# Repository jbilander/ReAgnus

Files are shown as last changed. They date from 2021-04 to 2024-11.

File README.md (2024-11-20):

# ReAgnus
A drop-in replacement PCB for the Amiga Agnus chip

***

Rev. 2D, design using a [PLCC-84 homebrew plug](https://github.com/jbilander/PLCC-84-plug)

<a href="images/ReAgnus_rev2d_pic1.jpg">
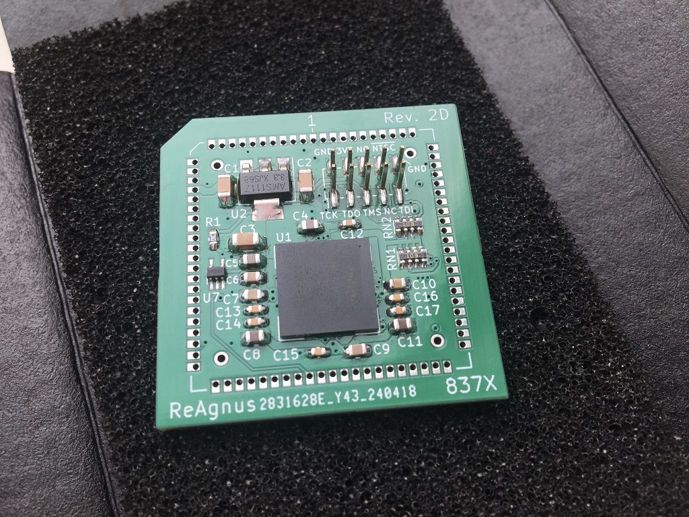
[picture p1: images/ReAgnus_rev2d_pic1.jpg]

</a>
<a href="images/ReAgnus_rev2d_pic2.jpg">
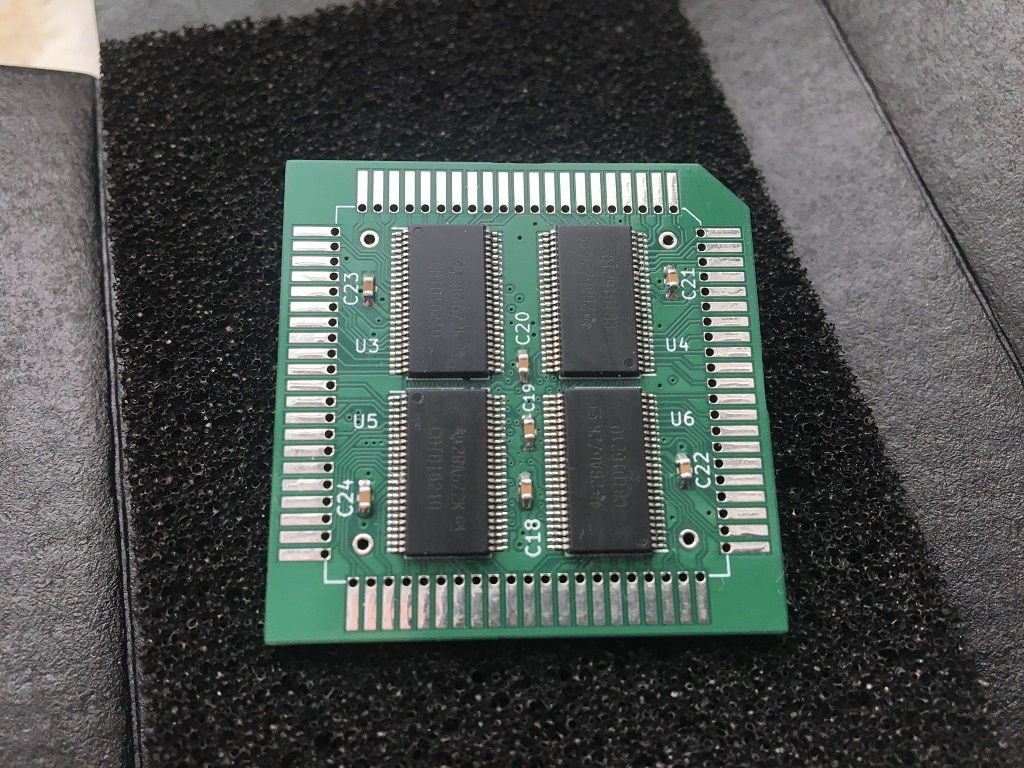
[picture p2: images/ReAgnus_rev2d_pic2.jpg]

</a>
<br />
<a href="images/ReAgnus_rev2d_pic3.jpg">
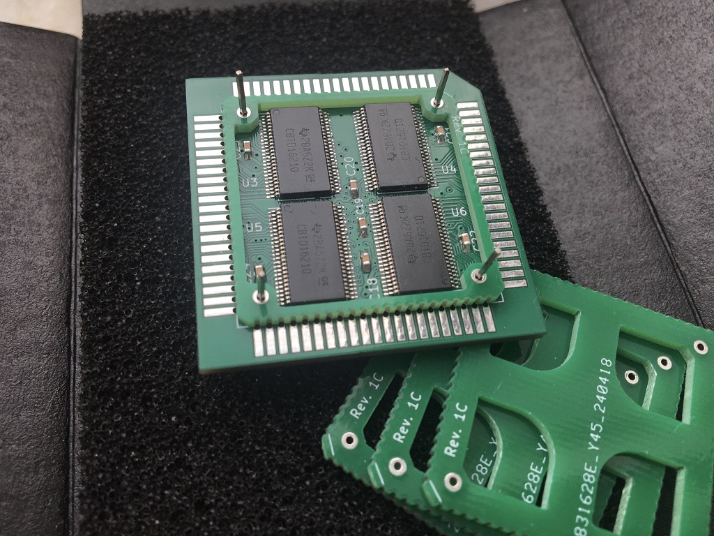
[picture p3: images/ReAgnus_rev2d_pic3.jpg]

</a>
<a href="images/ReAgnus_rev2d_pic4.jpg">
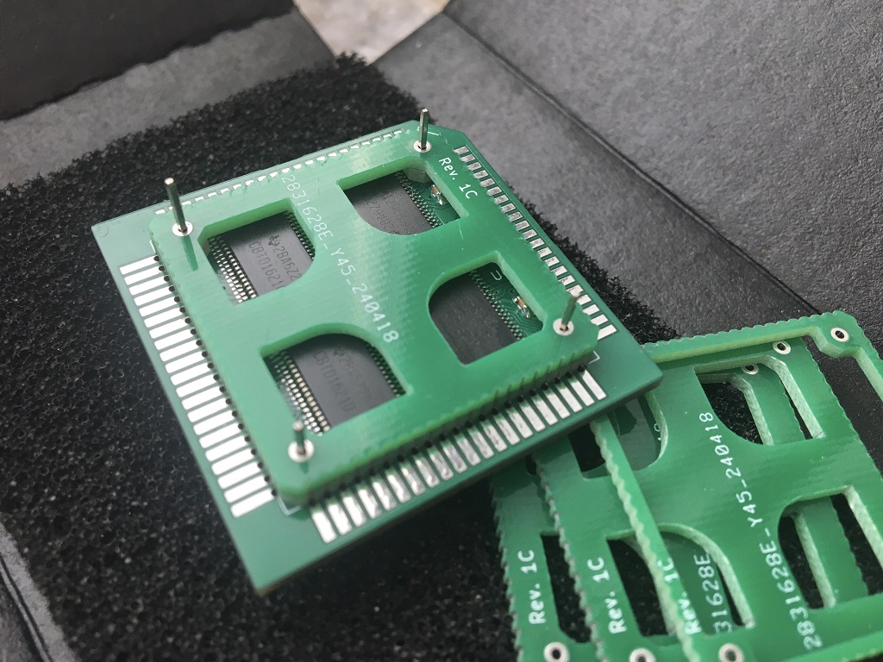
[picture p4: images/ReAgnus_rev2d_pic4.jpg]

</a>
<a href="images/ReAgnus_rev2d_pic5.jpg">
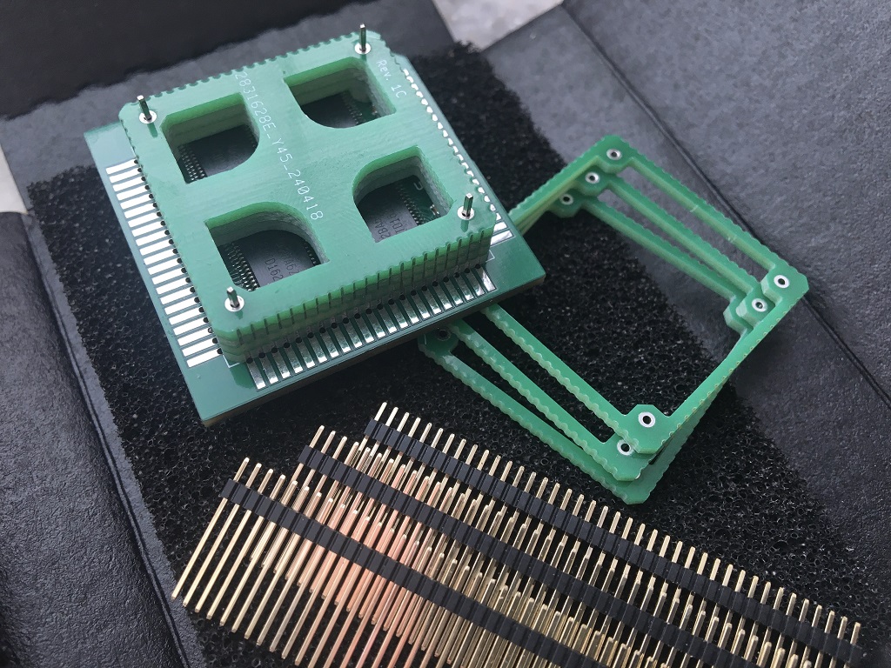
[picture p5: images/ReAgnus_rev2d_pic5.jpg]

</a>

***
FPGA pin assignment:

<a href="images/pin_assignment_rev2e.jpg">
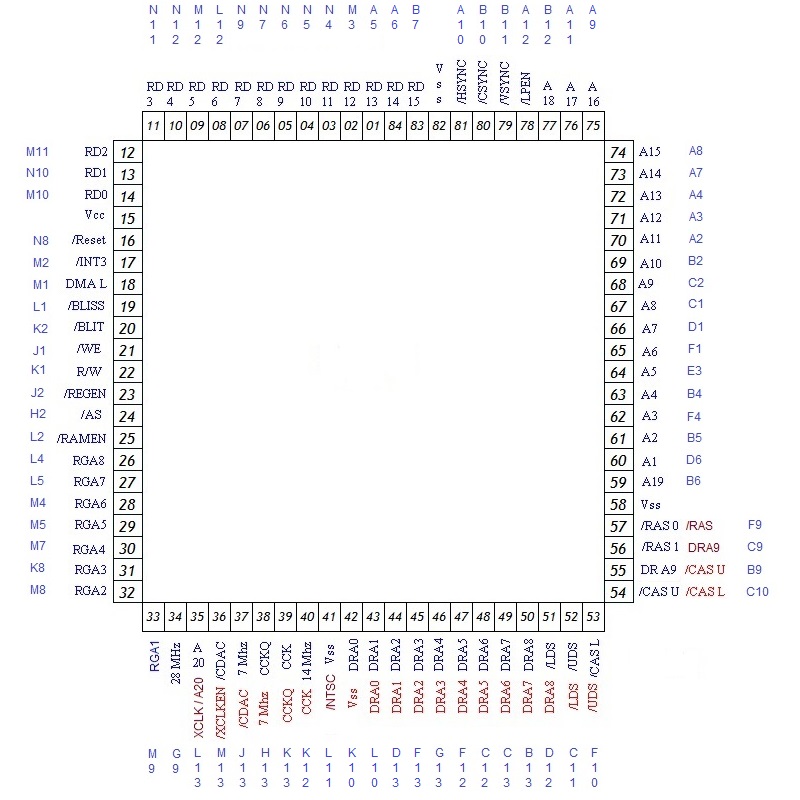
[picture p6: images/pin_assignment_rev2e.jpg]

</a>

***

Rev. 2B, design using a PLCC-84-plug
<br />
<br />

<a href="images/ReAgnus_rev2b_pic1.png">
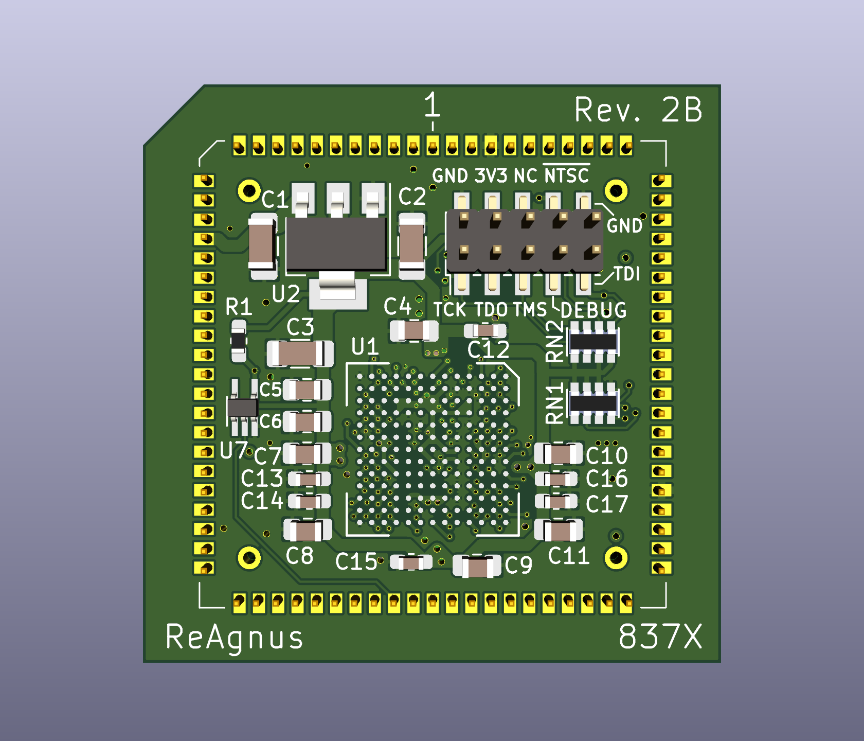
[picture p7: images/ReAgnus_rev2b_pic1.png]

</a>
<a href="images/ReAgnus_rev2b_pic2.png">
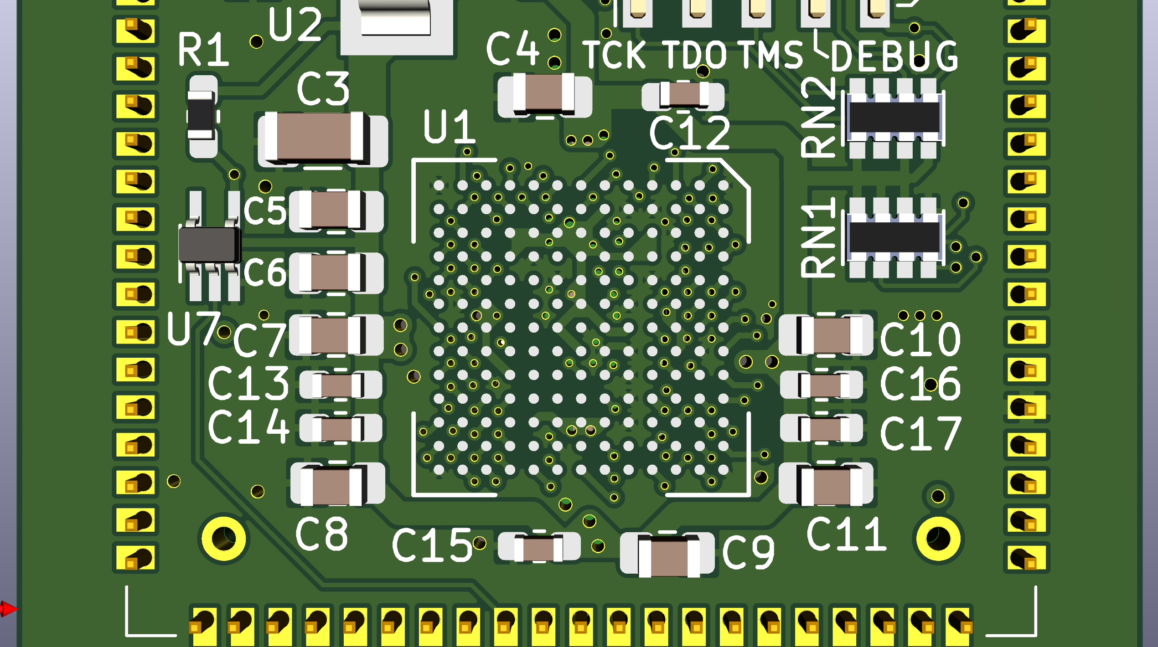
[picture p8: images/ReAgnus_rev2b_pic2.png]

</a>
<a href="images/ReAgnus_rev2b_pic9.png">
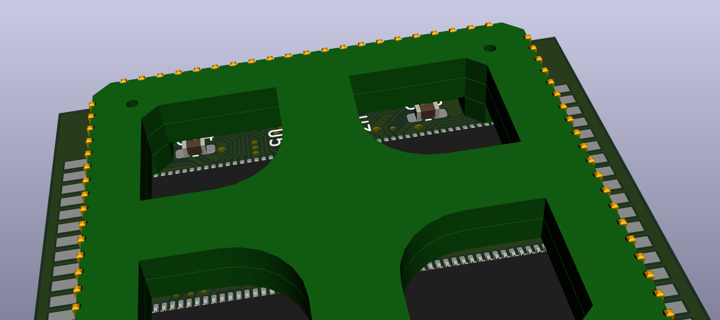
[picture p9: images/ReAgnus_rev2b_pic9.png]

</a>
<br />
<a href="images/ReAgnus_rev2b_pic7.png">
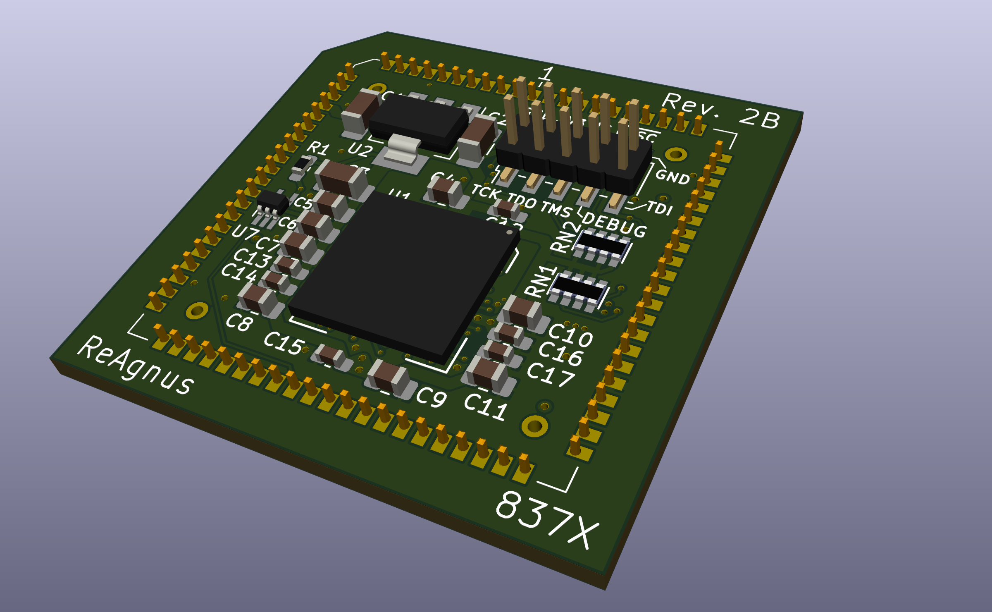
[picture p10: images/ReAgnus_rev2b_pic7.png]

</a>
<a href="images/ReAgnus_rev2b_pic8.png">
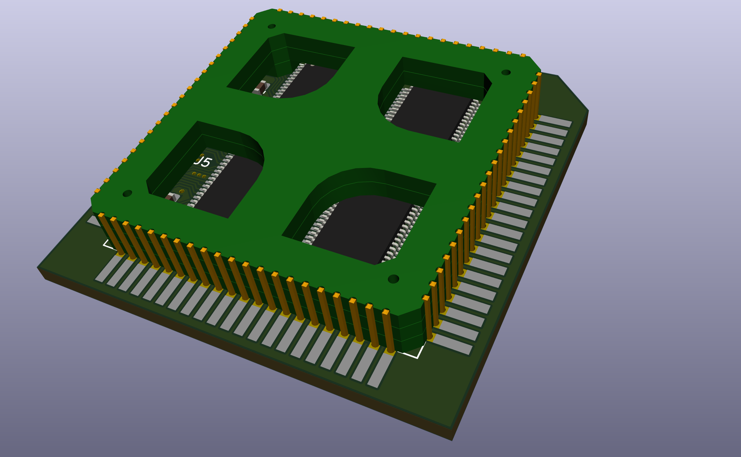
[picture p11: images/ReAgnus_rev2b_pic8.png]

</a>
<br />

***

When ordering from JLCPCB select:

Specify Layer Sequence: Yes

    L1(Top layer):    F_Cu.gbr
    L2(Inner layer1): GND_Cu.gbr
    L3(Inner layer2): VCC_Cu.gbr
    L4(Bottom layer): B_Cu.gbr

Remove Order Number: 

    Specify a location

This will notify JLC where to put the order number, they will replace the "JLCJLCJLCJLC" silkscreen label.

***

<a href="images/ReAgnus_rev2b_pic11.png">
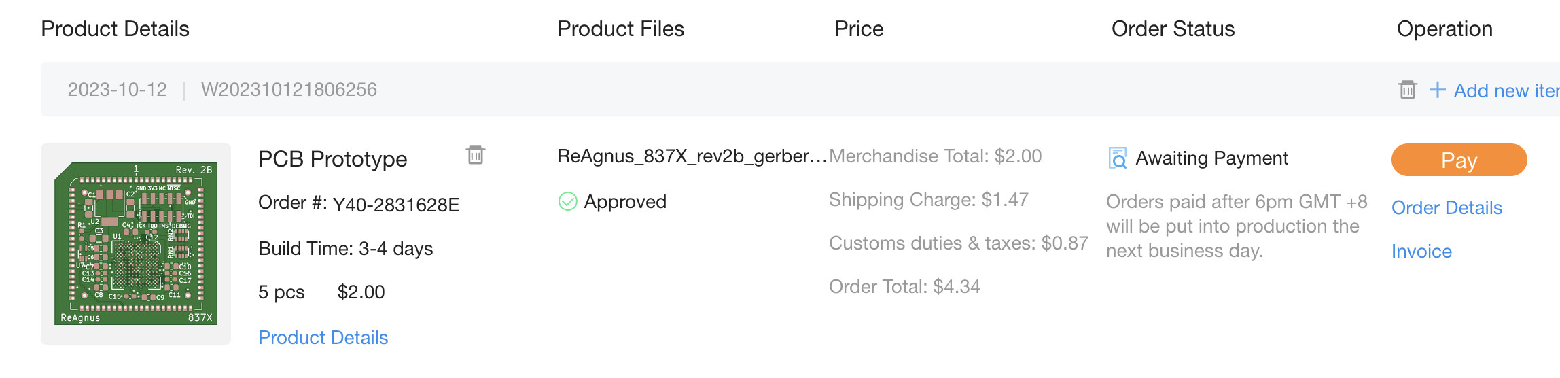
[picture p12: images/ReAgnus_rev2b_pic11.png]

</a>
<br />
<a href="images/ReAgnus_rev2b_pic10.png">
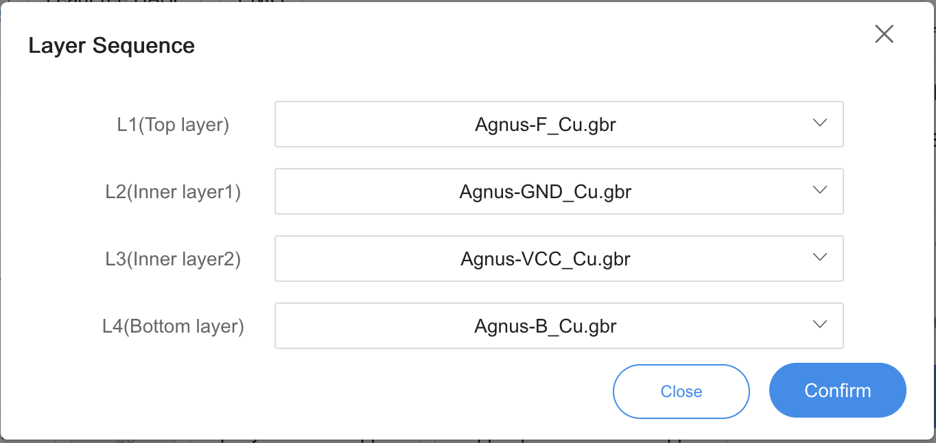
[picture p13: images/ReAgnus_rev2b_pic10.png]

</a>
<br />
<a href="images/ReAgnus_rev2b_pic4.png">
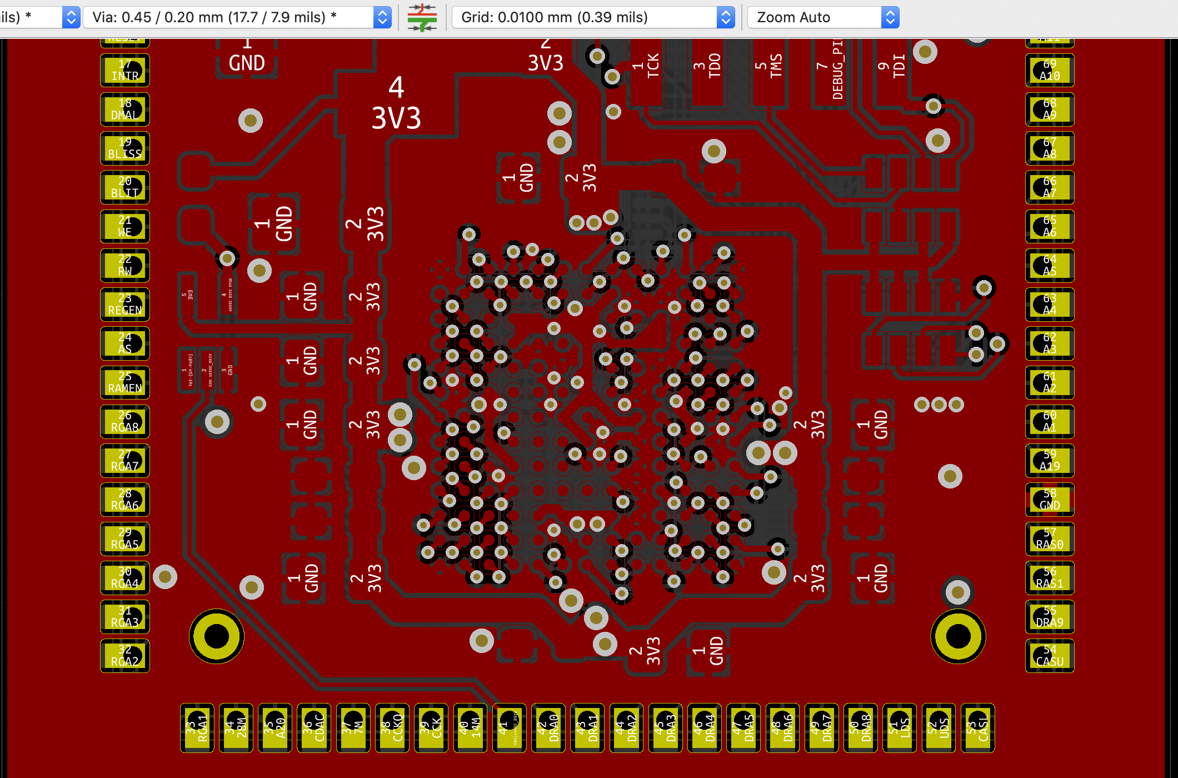
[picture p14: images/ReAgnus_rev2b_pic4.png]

</a>
<a href="images/ReAgnus_rev2b_pic5.png">
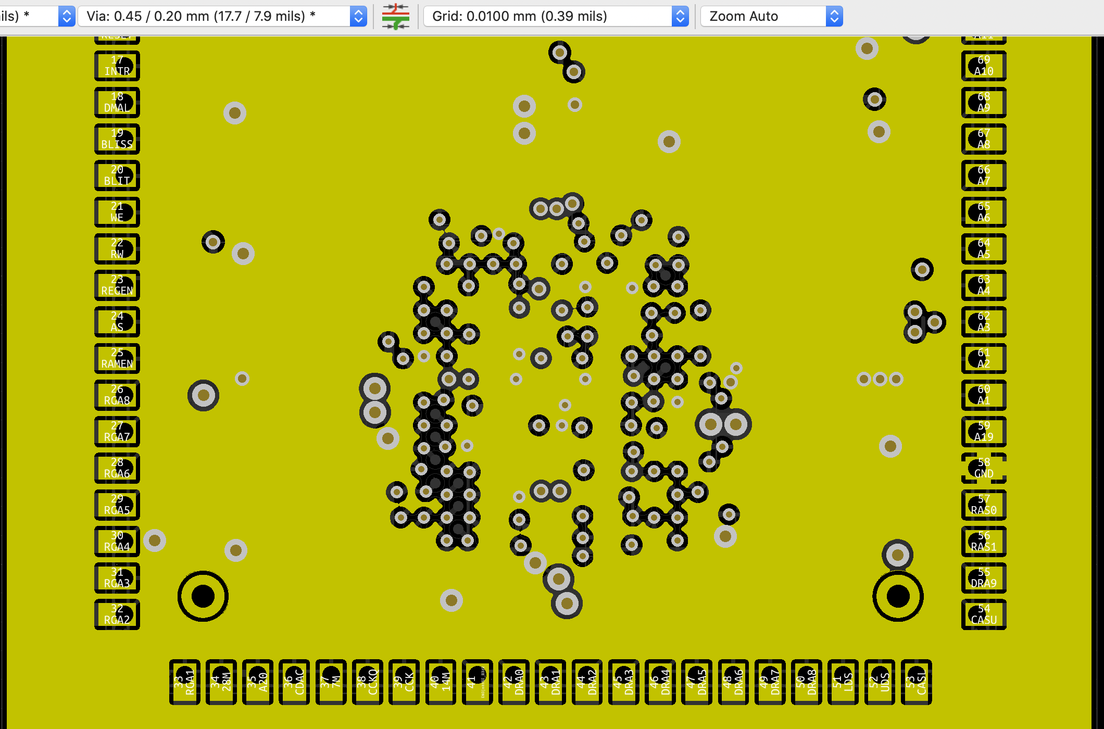
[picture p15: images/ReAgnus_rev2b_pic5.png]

</a>
<br />
<a href="images/ReAgnus_rev2b_pic6.png">
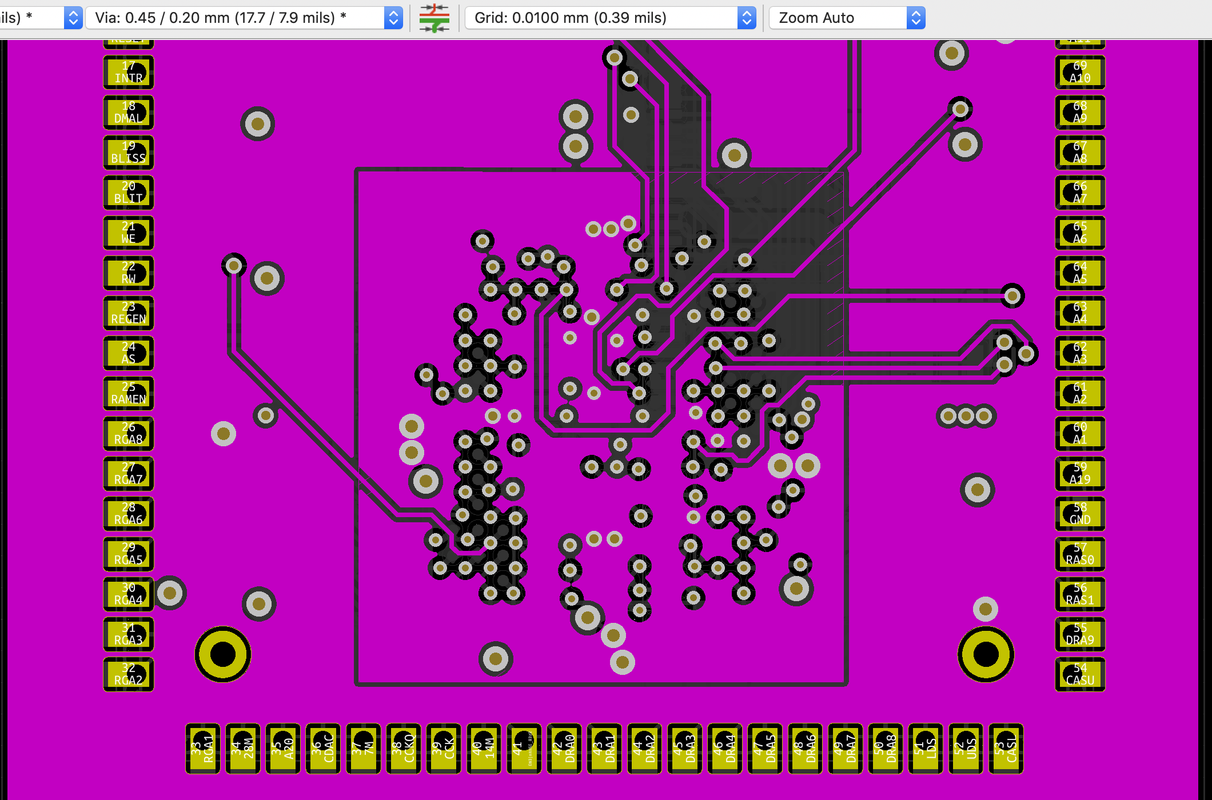
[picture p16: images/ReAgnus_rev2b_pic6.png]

</a>
<a href="images/ReAgnus_rev2b_pic3.png">
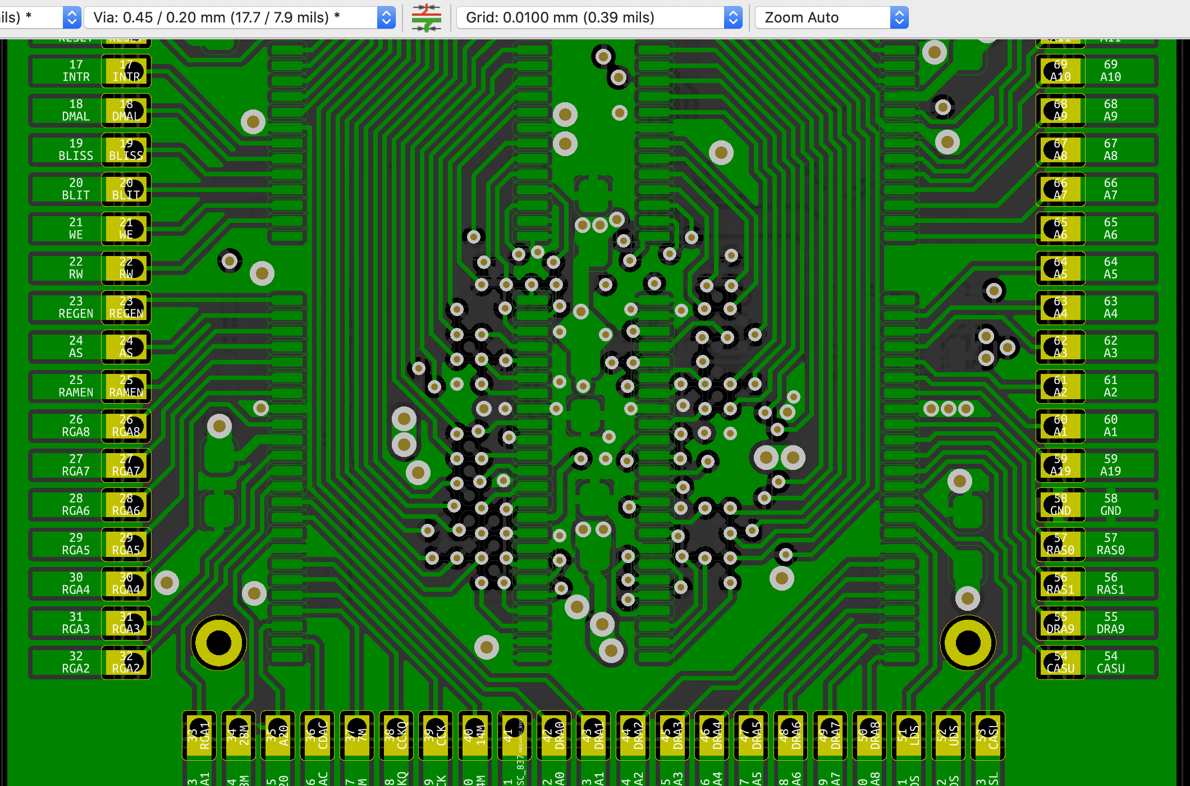
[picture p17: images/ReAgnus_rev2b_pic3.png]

</a>

***

Building Rev. 2B

<a href="images/ReAgnus_rev2b_pic12.jpg">
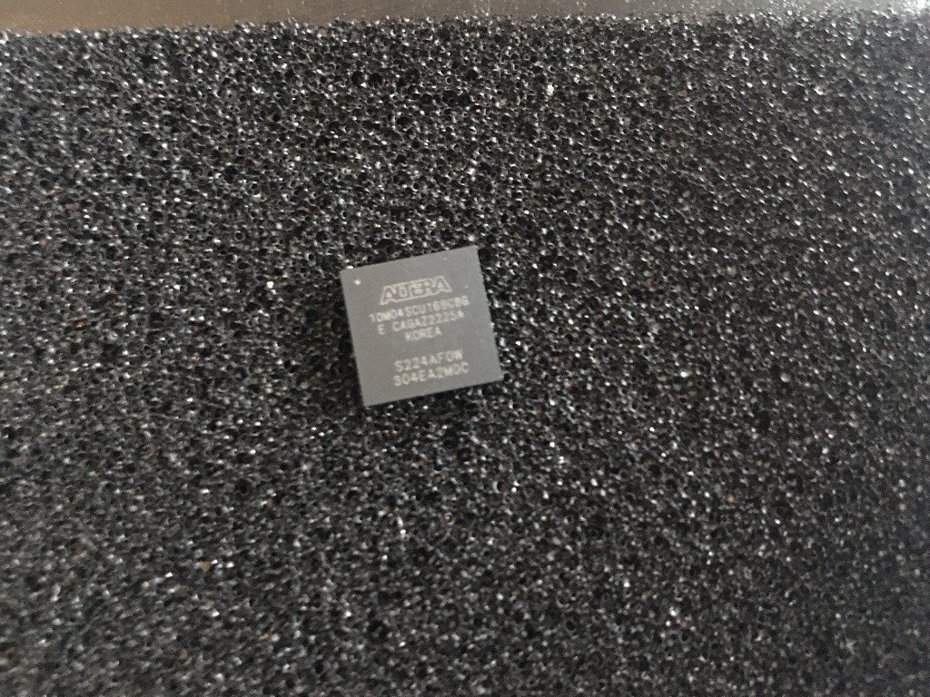
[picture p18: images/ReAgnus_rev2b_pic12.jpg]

</a>
<a href="images/ReAgnus_rev2b_pic13.jpg">
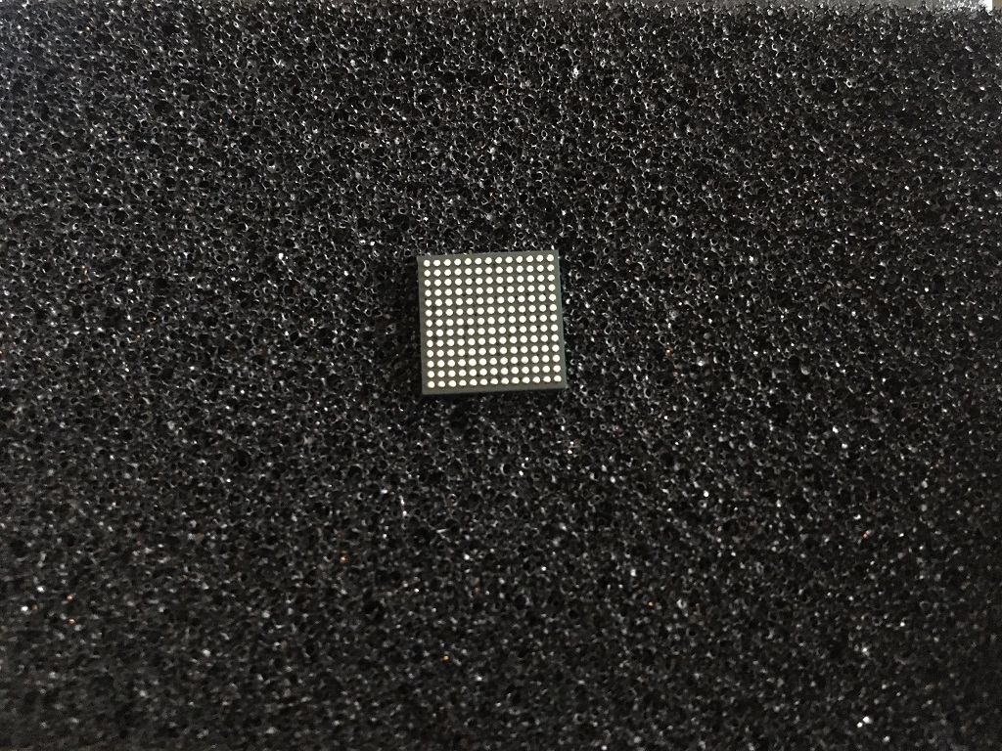
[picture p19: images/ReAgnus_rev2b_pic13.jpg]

</a>
<a href="images/ReAgnus_rev2b_pic14.jpg">
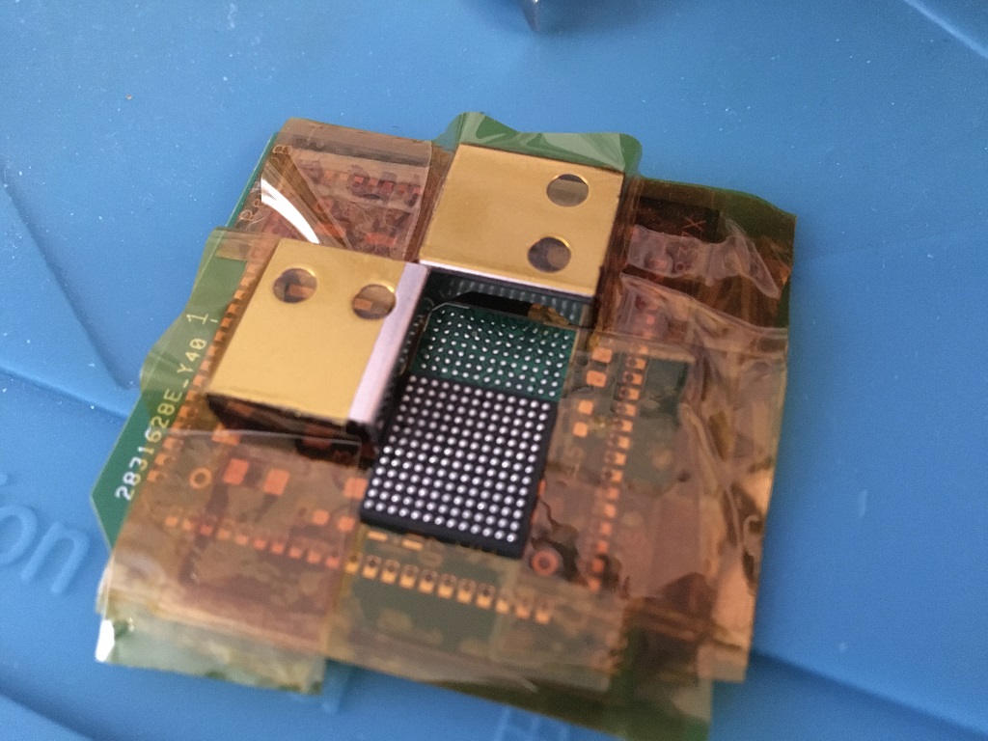
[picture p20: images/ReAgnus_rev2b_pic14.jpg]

</a>
<br />
<a href="images/ReAgnus_rev2b_pic15.jpg">
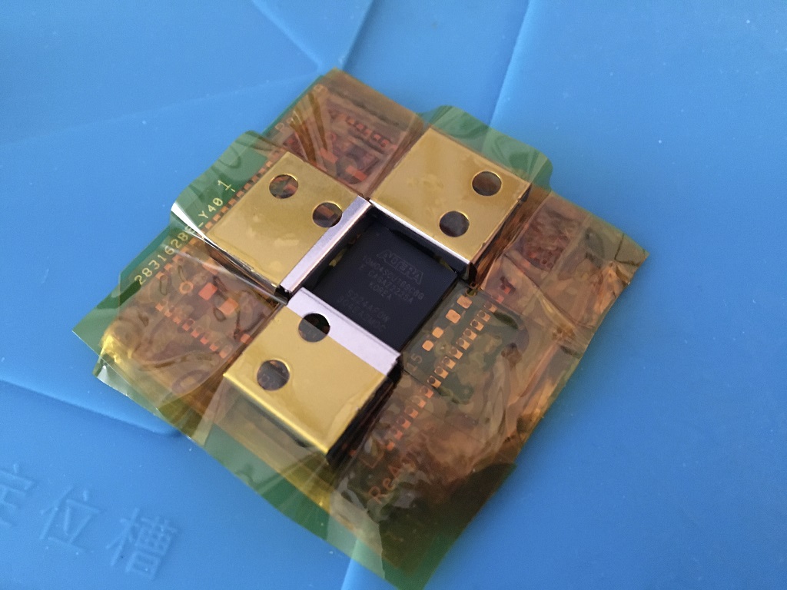
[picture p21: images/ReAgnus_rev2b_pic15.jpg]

</a>
<a href="images/ReAgnus_rev2b_pic16.jpg">
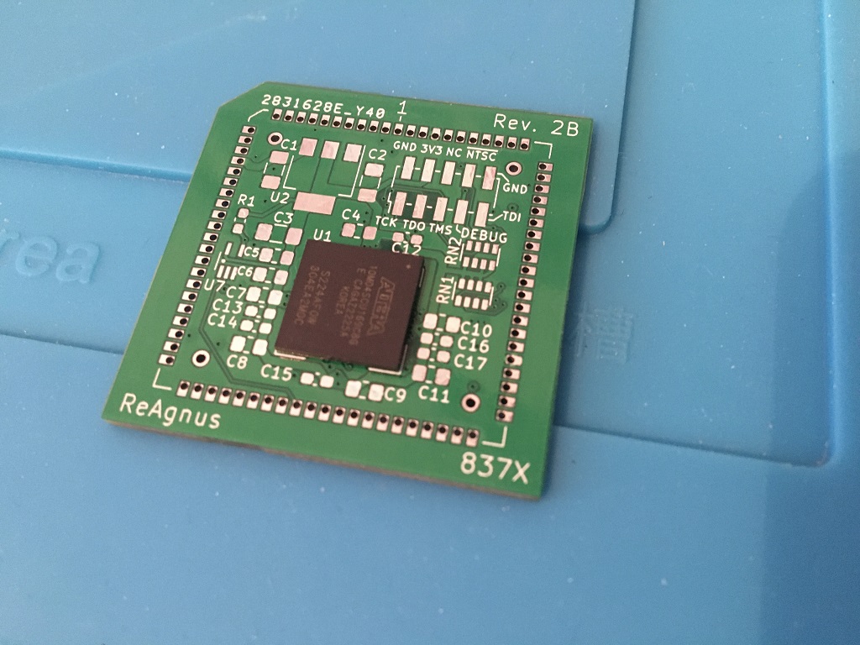
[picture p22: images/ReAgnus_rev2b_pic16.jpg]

</a>
<a href="images/ReAgnus_rev2b_pic17.jpg">
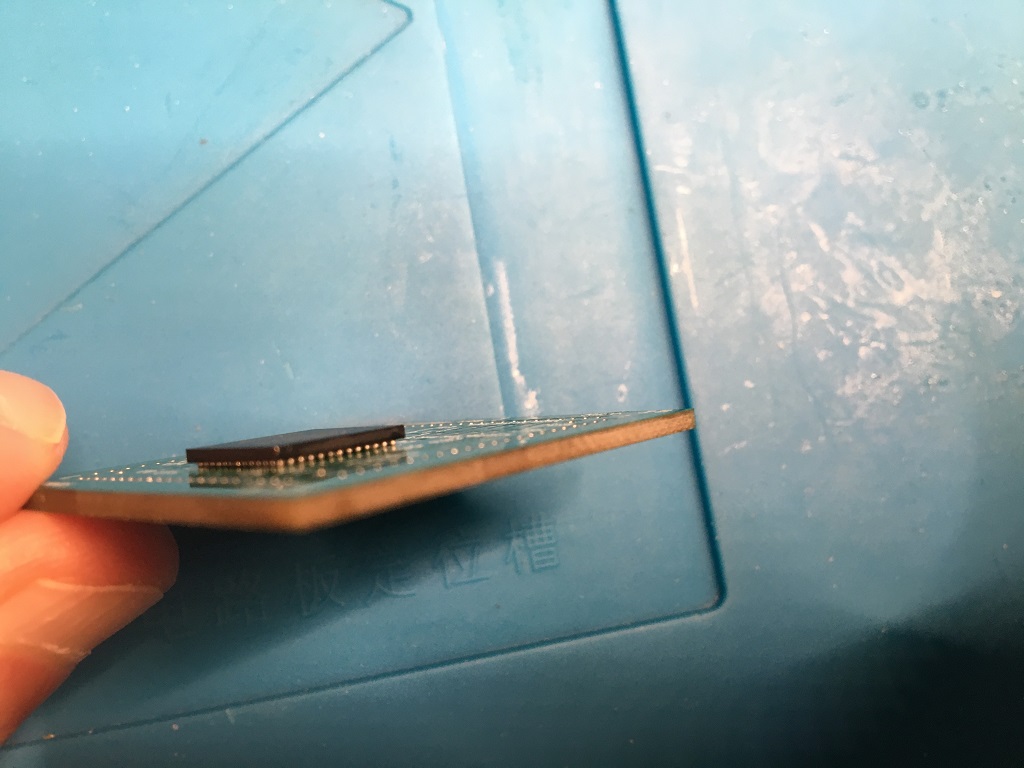
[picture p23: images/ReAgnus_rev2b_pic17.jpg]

</a>
<br />
<a href="images/ReAgnus_rev2b_pic18.jpg">
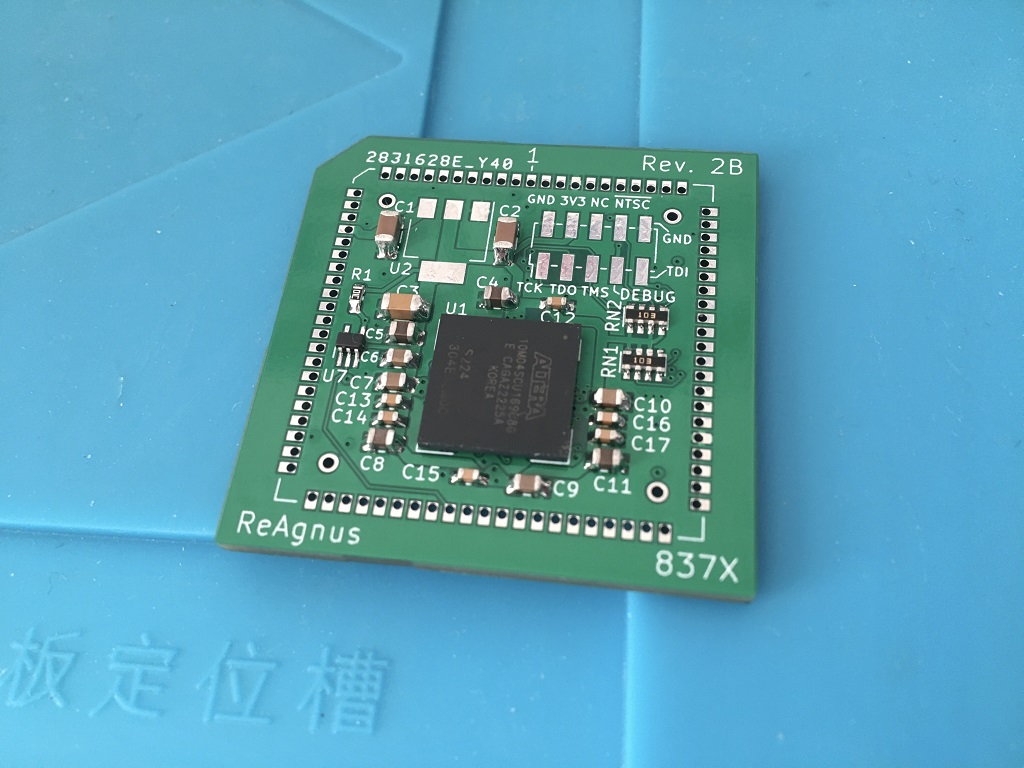
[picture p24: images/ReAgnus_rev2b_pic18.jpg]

</a>
<a href="images/ReAgnus_rev2b_pic19.jpg">
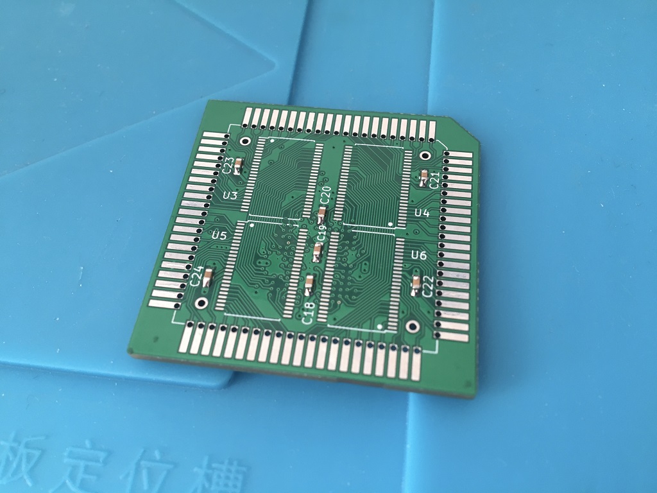
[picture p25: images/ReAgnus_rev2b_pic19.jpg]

</a>
<a href="images/ReAgnus_rev2b_pic20.jpg">
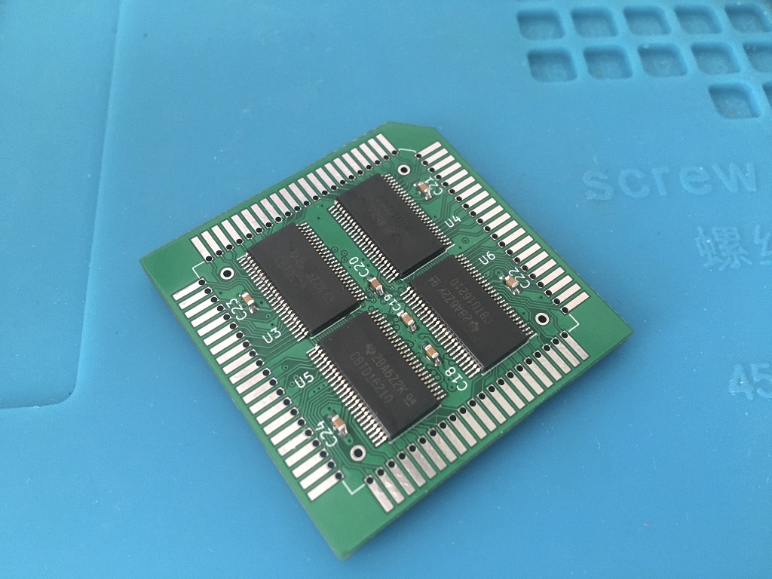
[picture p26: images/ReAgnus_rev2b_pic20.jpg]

</a>
<br />
<a href="images/ReAgnus_rev2b_pic21.jpg">
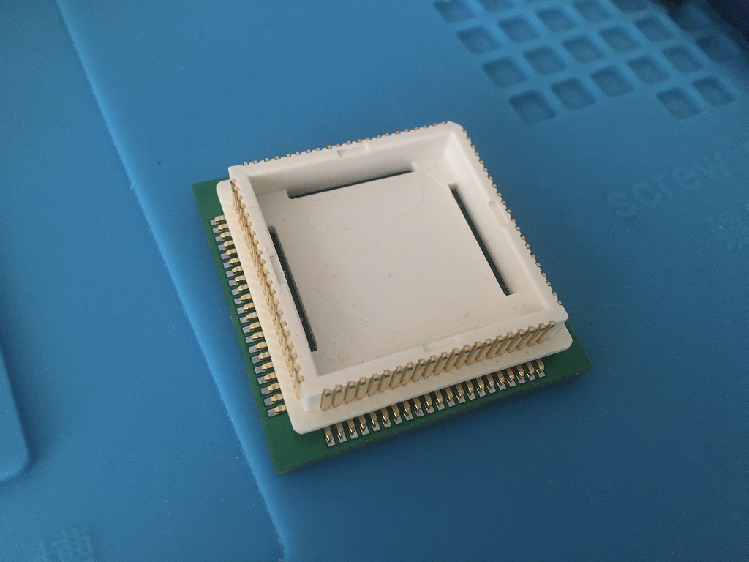
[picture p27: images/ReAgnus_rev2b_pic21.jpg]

</a>
<a href="images/ReAgnus_rev2b_pic22.jpg">
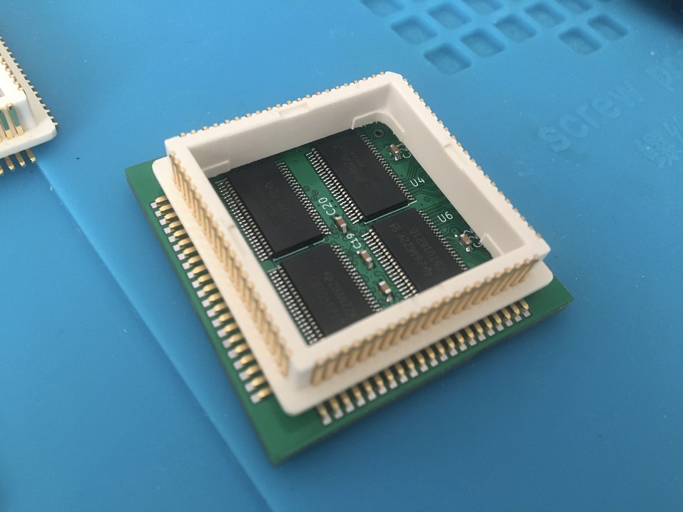
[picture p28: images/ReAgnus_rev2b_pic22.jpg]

</a>
<a href="images/ReAgnus_rev2b_pic23.jpg">
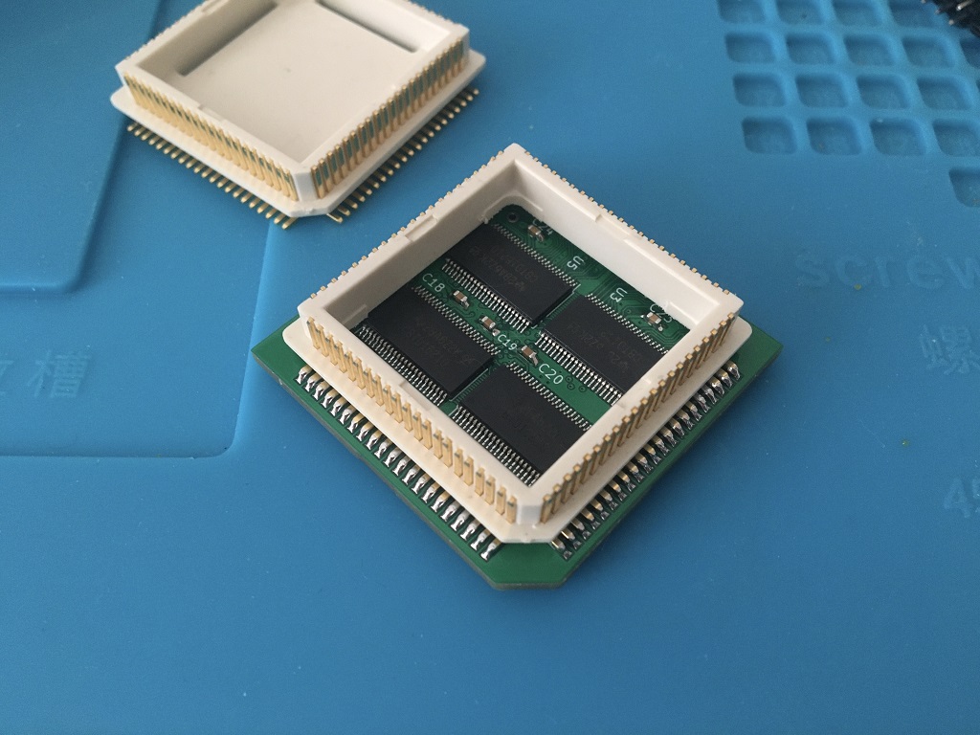
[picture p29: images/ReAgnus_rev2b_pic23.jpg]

</a>
<br />
<a href="images/ReAgnus_rev2b_pic24.jpg">
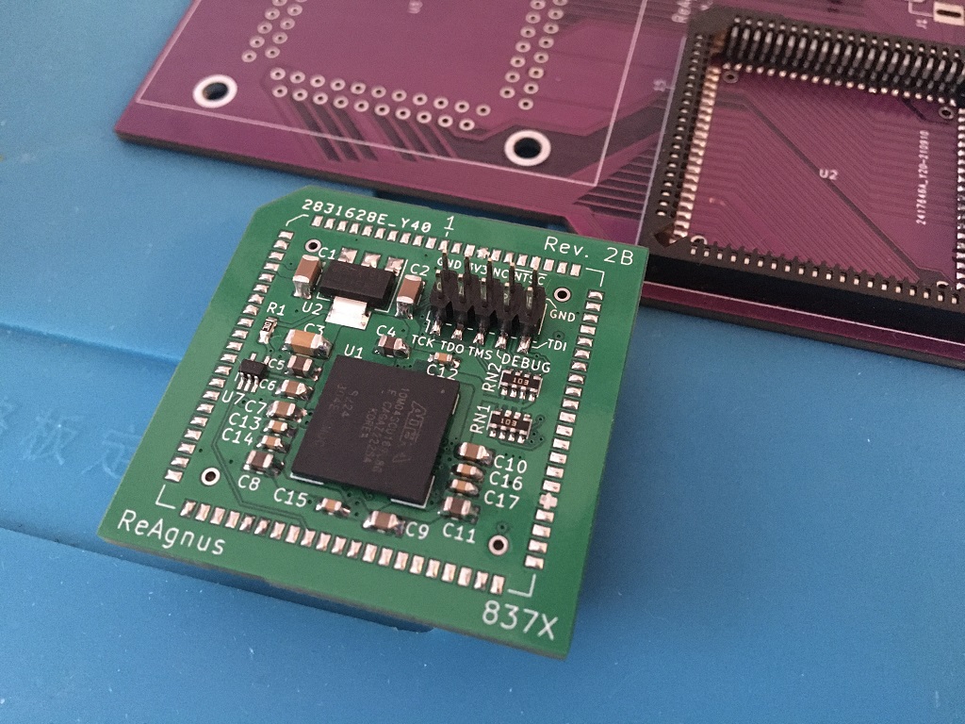
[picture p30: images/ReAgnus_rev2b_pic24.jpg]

</a>

***

<br />
REV 1A
<br />
<a href="images/screenshot_pic1.png">
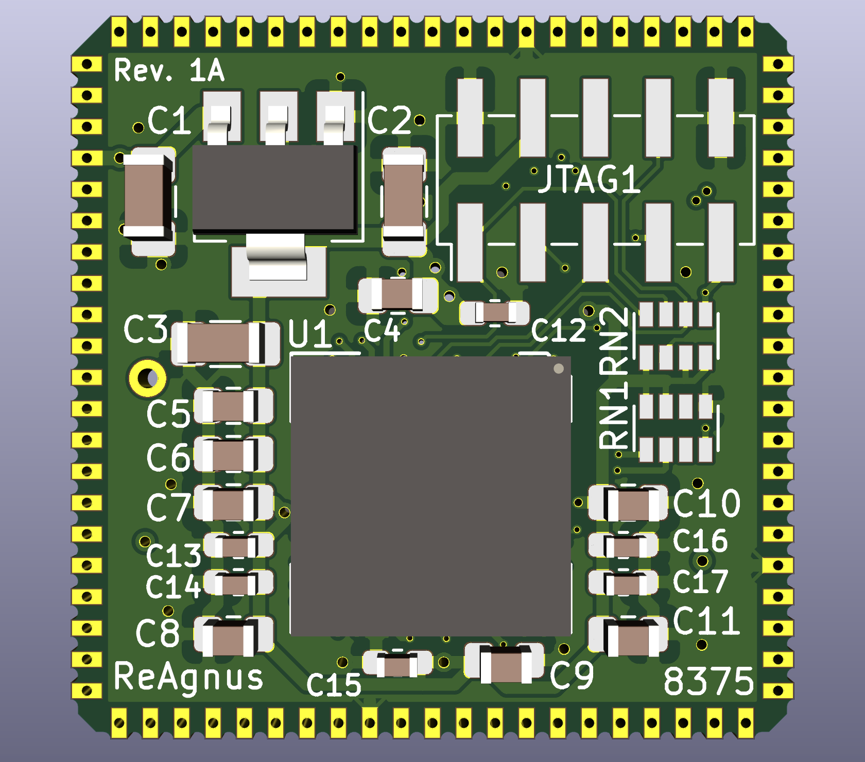
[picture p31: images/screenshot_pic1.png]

</a>
<a href="images/screenshot_pic2.png">
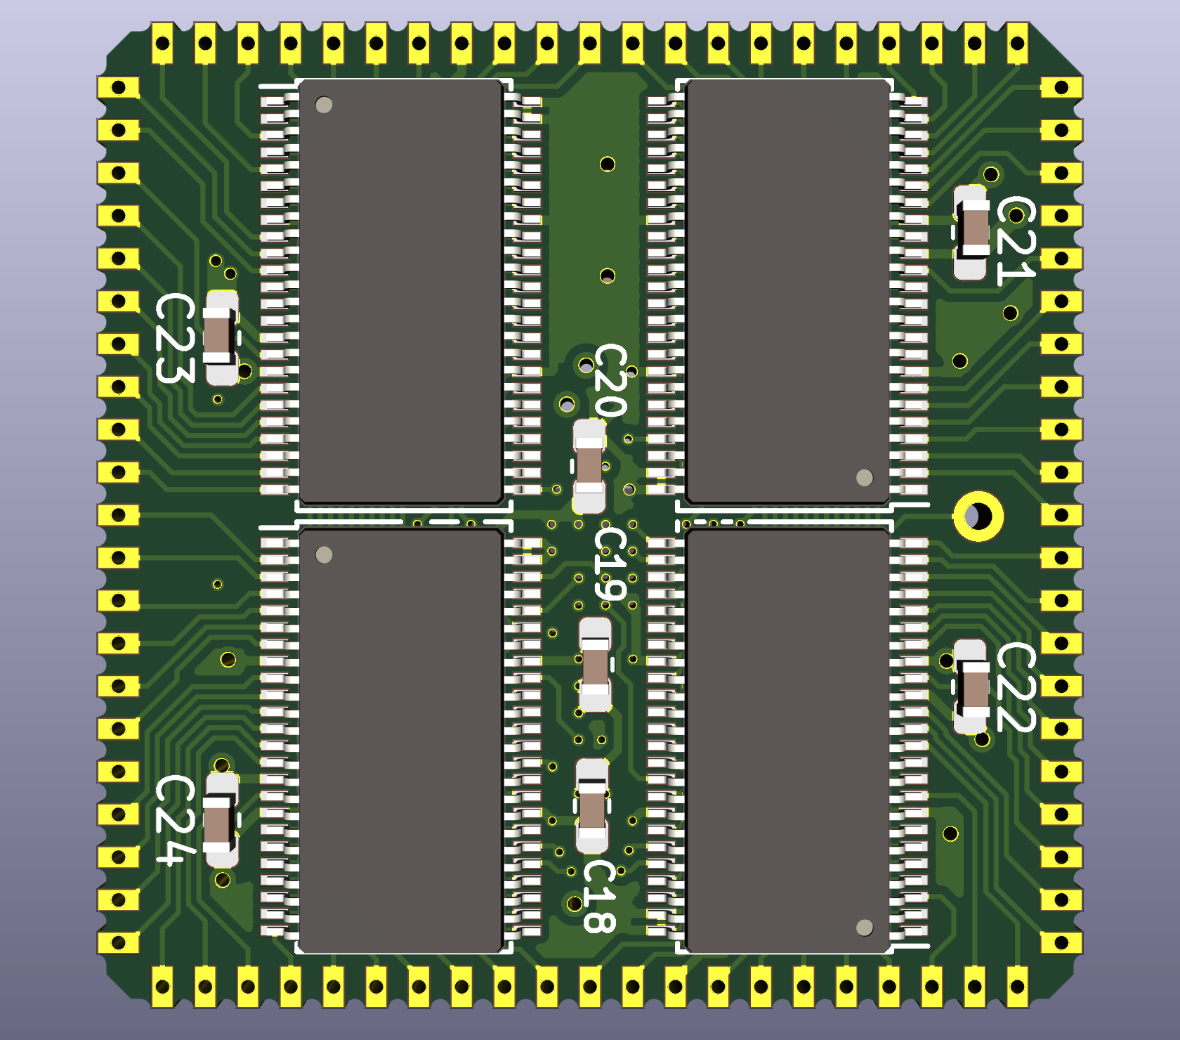
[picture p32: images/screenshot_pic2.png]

</a>

<br />
REV 1B
<br />
<a href="images/screenshot_pic3.png">
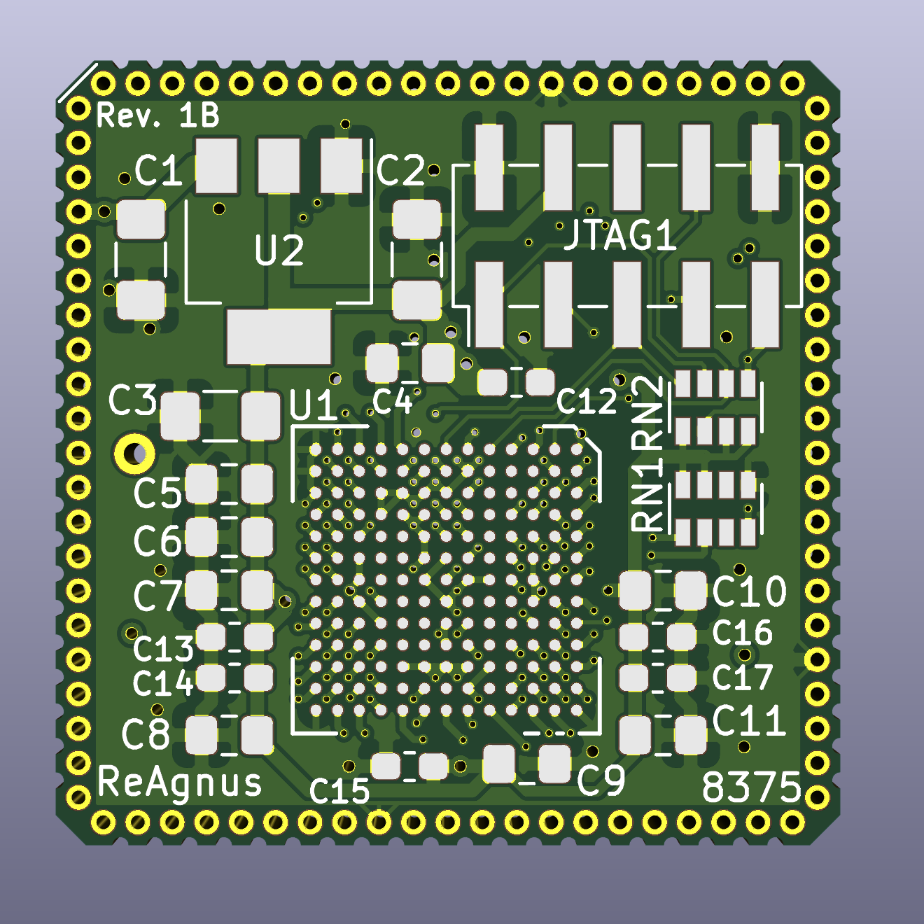
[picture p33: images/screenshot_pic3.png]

</a>
<a href="images/screenshot_pic4.png">
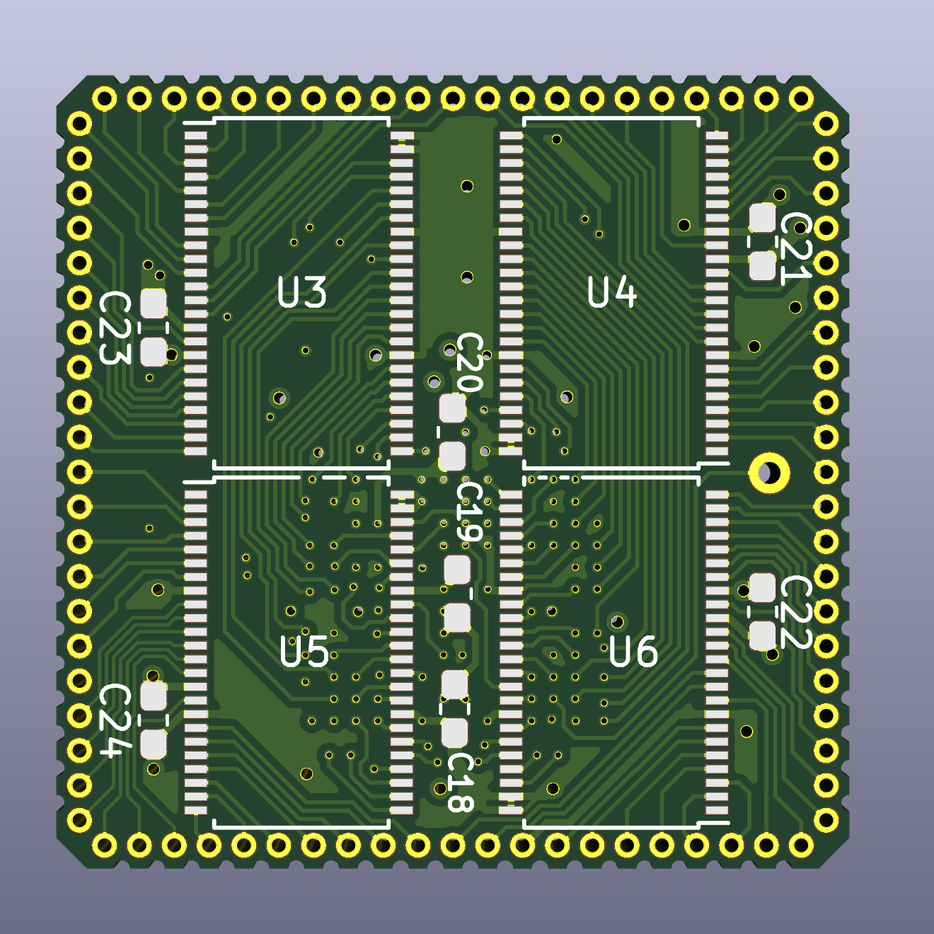
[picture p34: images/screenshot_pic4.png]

</a>

<br />
<a href="images/ReAgnus_four_in_one.jpg">
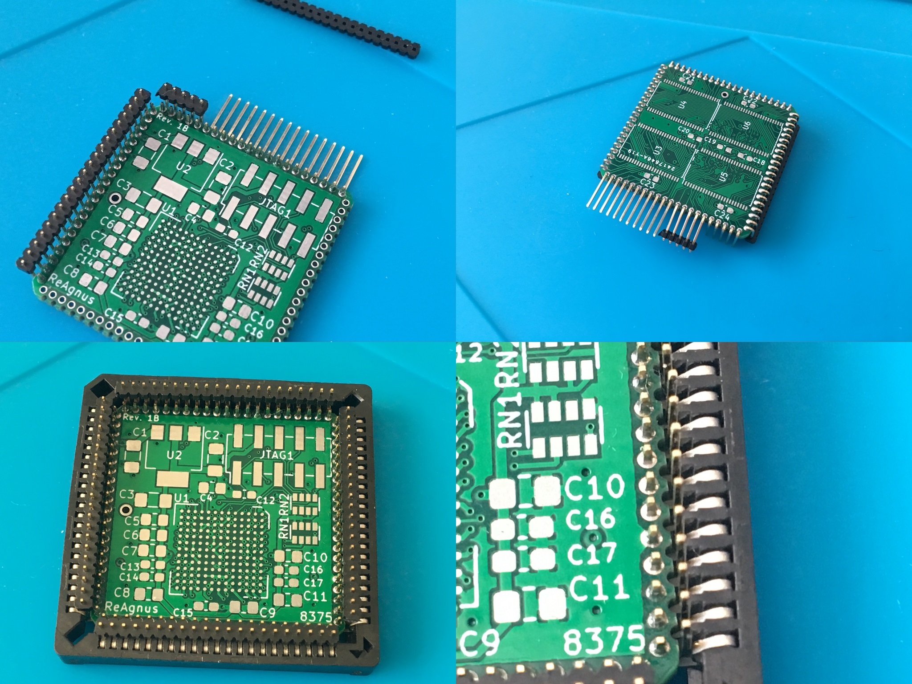
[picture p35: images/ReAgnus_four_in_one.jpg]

</a>
<a href="images/screenshot_pic5.png">
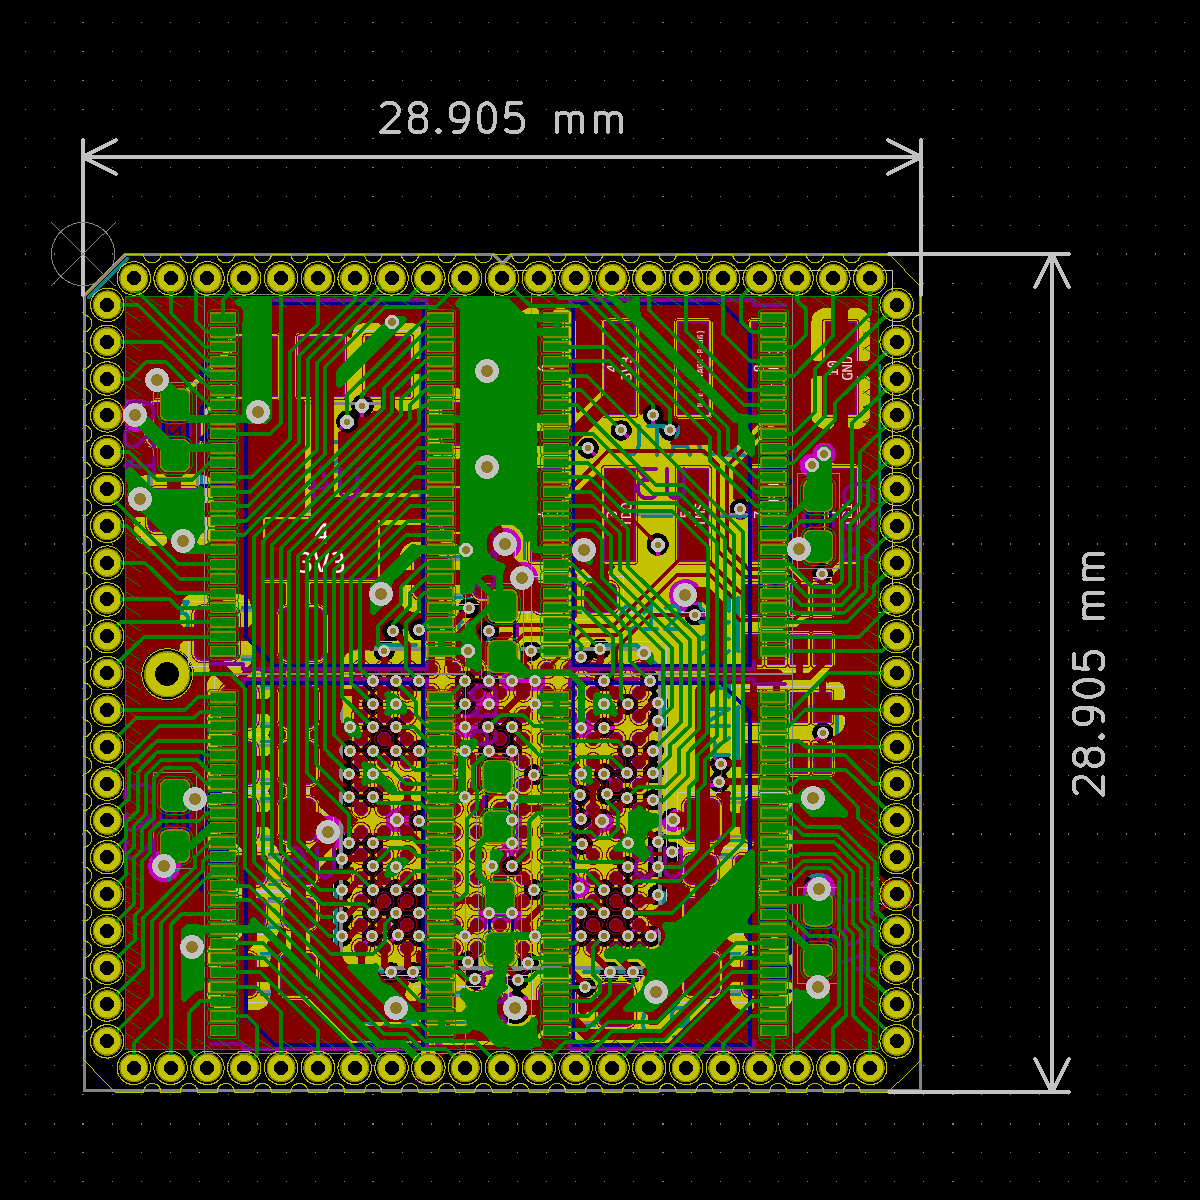
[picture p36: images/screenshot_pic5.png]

</a>

***

<br />
<a href="images/ReAgnus_pic1.jpg">
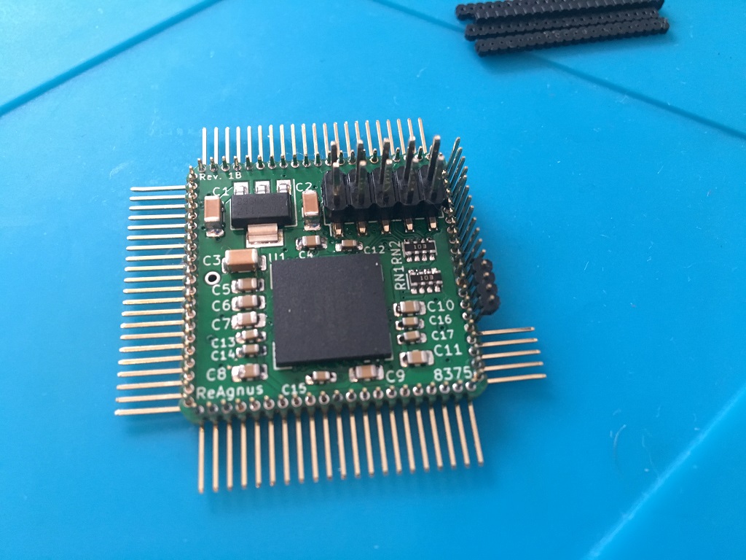
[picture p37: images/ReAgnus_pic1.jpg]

</a>
<a href="images/ReAgnus_pic2.jpg">
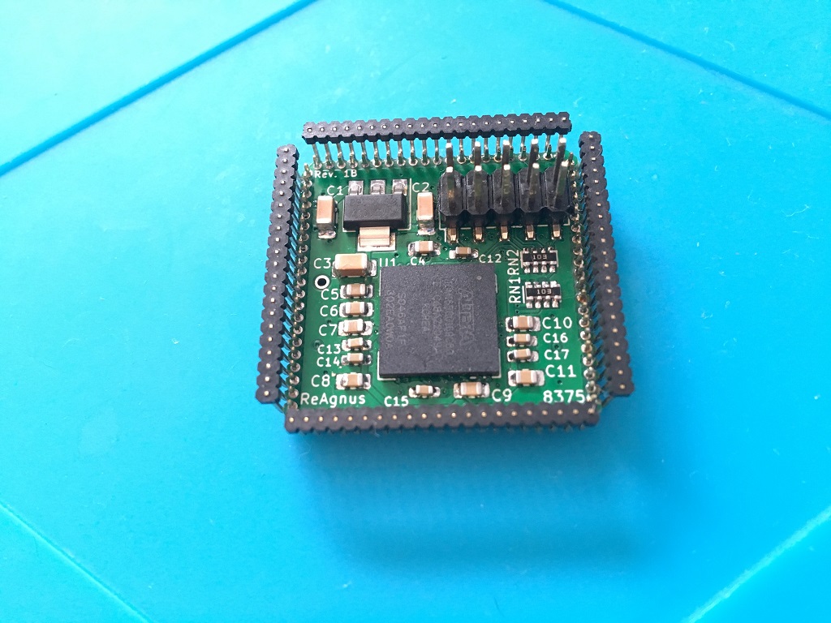
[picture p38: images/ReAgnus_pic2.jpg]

</a>
<a href="images/ReAgnus_pic3.jpg">
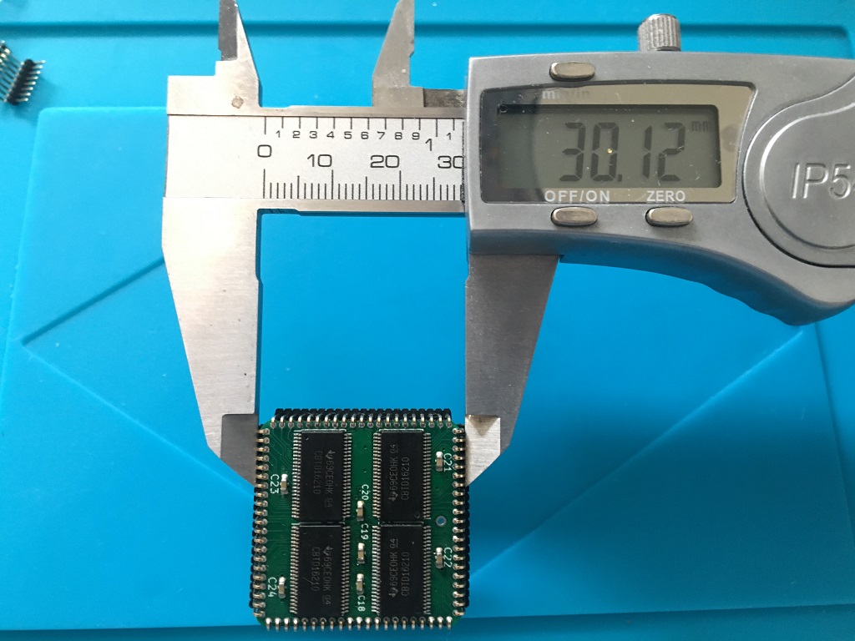
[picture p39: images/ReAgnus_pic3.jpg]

</a>

***

BOM Rev. 2E (837X - Universal Agnus PCB design)
---------
Position  | Name/Value   | Package | Notes
-|-|-|-|
U1 | 10M04SCU169C8G | BGA-169 11.0x11.0mm_Layout13x13 | FPGA Intel MAX 10 [10M04SCU169C8G](https://www.mouser.com/ProductDetail/989-10M04SCU169C8G)
U2 | LM1117-3.3 | SOT-223 | Low-Dropout Linear Regulator 3.3 Volt
U3-U6 | SN74CBTD16210 | TSSOP-48 6.1x12.5mm_P0.5mm | 20-BIT FET Bus switch with level shifting, high-speed TTL-compatible. [74CBTD16210DGGR](https://www.mouser.com/ProductDetail/595-74CBTD16210DGGR)
U7 | 74LVC1G07 | 5-TSSOP, SC-70-5, SOT-353 (2.0 mm × 1.25mm) | [74LVC1G07](https://www.mouser.com/ProductDetail/621-74LVC1G07SE-7)
U8 | Winslow PLCC-84 Plug | PLCC-84 Plug | Optionally use a DIY-plug (stacked PCBs)
U9 | PLCC-84_TH_pin_holes | Agnus_TH_plug_pins | Pins that could be used with the DIY-plug rev1d PCBs for manual fitting, L8.7mm [Aliexpress](https://www.aliexpress.com/item/32893608810.html)
R1 | Resistor 4.7k or 10k Ω | 0603 | Pull-up resistor for PAL/NTSC selection for 8372 Agnus FPGA firmware/pinout
R2 | Resistor 4.7k or 10k Ω | 0603 | Pull-up resistor for pin 41 (PAL/NTSC-selector for A500 Rev.6A/A2000/A3000-pinout) since A500 Rev.6A doesn't have pull-up on motherboard like A2000/A3000/A3000T have. Only needed for A500 Rev.6A. but doesn't hurt to populate anyway.
RN1 | CAY16-103J4LF RES ARRAY 4 Resistors 10k Ω | 1206 | [CAY16-103J4LF](https://www.mouser.com/ProductDetail/652-CAY16-103J4LF)
RN2 | CAY16-103J4LF RES ARRAY 4 Resistors 10k Ω | 1206 | --"--
C1-3 | Capacitor 10uF | 1206 | 
C4,C5,C8,C11 | Capacitor 1uF | 0805 | 
C6,C7,C9,C10 | Capacitor 0.1uF = 100nF | 0805 | 
C12-C19 | Capacitor 0.01uF = 10nF | 0603 |
C20 | Capacitor 0.1uF = 100nF | 0603 |
C21-C24 | Capacitor 0.01uF = 10nF | 0603 |
JTAG | SMT Pin Header Male | SMT 2 x 5 Pin 2.0mm pitch |

***

[][cc-by-sa]

This work is licensed under a
[Creative Commons Attribution-ShareAlike 4.0 International License][cc-by-sa].

[][cc-by-sa]

[cc-by-sa]: http://creativecommons.org/licenses/by-sa/4.0/
[cc-by-sa-image]: https://licensebuttons.net/l/by-sa/4.0/88x31.png
[cc-by-sa-shield]: https://img.shields.io/badge/License-CC%20BY--SA%204.0-lightgrey.svg

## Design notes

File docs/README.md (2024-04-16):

### FPGA pinout 

Intel 10M16SCU169C8G vs Gowin GW1N-UV9UG169
---------
Type  | CFG   | U169 | 8375/8372 | Agnus Pin  | CFG   | Type |
-|-|-|-|-|-|-|
IO|-|A5|DRD13|1|-|IOT19A|
IO|PLL_L_CLKOUTn|M3|DRD12|2|-|IOL26B|
IO|-|N4|DRD11|3|-|IOB8B|
IO|-|N5|DRD10|4|-|IOB8A|
IO|-|N6|DRD9|5|-|IOB11B|
IO|-|N7|DRD8|6|-|IOB13B|
IO|-|N9|DRD7|7|-|IOB35A|
IO|-|L12|DRD6|8|-|IOR24B|
IO|-|M12|DRD5|9|GCLKT_4|IOB29A|
IO|-|N12|DRD4|10|-|IOB23A|
IO|VREFB3N0|N11|DRD3|11|-|IOB23B|
IO|CLK6n|M11|DRD2|12|-|IOB41B|
IO|-|N10|DRD1|13|-|IOB35B|
IO|-|M10|DRD0|14|-|IOB45B|
-|-|-|VCC|15|-|-|
IO|-|N8|RESET_n|16|-|IOB13A|
IO|-|M2|INT3_n|17|-|IOL24A|
IO|-|M1|DMAL|18|-|IOL24B|
IO|VREFB2N0|L1|BLISS_n|19|-|IOL23A|
IO|-|K2|BLIT_n|20|-|IOL27A|
IO|-|J1|WE_n|21|-|IOL22B|
IO|-|K1|RW&#773;|22|-|IOL27B|
IO|-|J2|REGEN_n|23|-|IOL22A|
IO|-|H2|AS_n|24|-|IOL20B|
IO|-|L2|RAMEN_n|25|-|IOL23B|
IO|-|L4|RGA8|26|-|IOB2A|
IO|-|L5|RGA7|27|-|IOB2B|
IO|-|M4|RGA6|28|-|IOB4B|
IO|-|M5|RGA5|29|-|IOB4A|
IO|-|M7|RGA4|30|-|IOB11A|
IO|CLK7p|K8|RGA3|31|-|IOB43A|
IO|-|M8|RGA2|32|-|IOB17B|
IO|-|M9|RGA1|33|-|IOB17A|
IO|CLK2p|G9|28M|34|GCLKT_3|IOR17A|
IO|-|L13|A20/(XCLK/A20)|35|-|IOR21A|
IO|-|M13|CDAC_n/XCLKEN_n|36|GCLKC_4|IOB29B|
IO|-|J13|7M/CDAC_n|37|DIN/CLKHOLD_N|IOR15A|
IO|-|H13|CCKQ/7M|38|DOUT/WE_N|IOR15B|
IO|VREFB5N0|K13|CCK/CCKQ|39|-|IOR21B|
IO|-|K12|14M/CCK|40|-|IOR22A|
IO|CLK6p|L11|GND/NTSC_n_8372|41 (10k pull-up)|-|IOB41A|
IO|RUP|K10|DRA0/GND|42|-|IOR26A|
IO|-|L10|DRA1/DRA0|43|-|IOB45A|
IO|VREFB6N0|D13|DRA2/DRA1|44|-|IOR7B|
IO|CLK3p|F13|DRA3/DRA2|45|GCLKT_2|IOR9A|
IO|-|G13|DRA4/DRA3|46|FASTRD_N/D3|IOR13A|
IO|-|F12|DRA5/DRA4|47|MCS_N/D5|IOR12A|
IO|-|C12|DRA6/DRA5|48|RPLL_T_IN|IOR5A|
IO|-|C13|DRA7/DRA6|49|-|IOR7A|
IO|-|B13|DRA8/DRA7|50|-|IOR4A|
IO|-|D12|LDS_n/DRA8|51|-|IOR2A|
IO|-|C11|UDS_n/LDS_n|52|RPLL_C_IN|IOR5B|
IO|DPCLK2|F10|CASL_n/UDS_n|53|-|IOR8B|
IO|CLK5p|C10|CASU_n/CASL_n|54|-|IOT35A|
IO|DEV_CLRn|B9|DRA9/CASU_n|55|-|IOT31B|
IO|CLK5n|C9|RAS1_n/DRA9|56|-|IOT35B|
IO|DPCLK3|F9|RAS0_n/RAS_n|57|-|IOR8A|
-|-|-|GND|58|-|-|
IO|-|B6|A19|59|-|IOT23A|
IO|CRC_ERROR|D6|A1|60|-|IOT15B|
IO|-|B5|A2|61|-|IOT23B|
IO|JTAGEN|E5|NC|62|JTAGSEL_N/LPLL_T_IN|IOL5A|
IO|-|B4|A4|63|-|IOT13B|
IO|-|E3|A5|64|-|IOL4B|
IO|-|F1|A6|65|-|IOL8B|
IO|-|D1|A7|66|-|IOL2B|
IO|-|C1|A8|67|LPLL_C_FB|IOL6B|
IO|-|C2|A9|68|-|IOL2A|
IO|-|B2|A10|69|-|IOT16B|
IO|-|A2|A11|70|-|IOT16A|
IO|-|A3|A12|71|-|IOT17B|
IO|-|A4|A13|72|-|IOT17A|
IO|-|A7|A14|73|-|IOT25A|
IO|-|A8|A15|74|-|IOT33A|
IO|-|A9|A16|75|-|IOT33B|
IO|-|A11|A17|76|GCLKC_1|IOT29B|
IO|-|B12|A18|77|RPLL_T_FB|IOR6A|
IO|-|A12|LPEN_n|78|-|IOR4B|
IO|-|B11|VSYNC_n|79|RPLL_C_FB|IOR6B|
IO|-|B10|CSYNC_n|80|-|IOT31A|
IO|-|A10|HSYNC_n|81|GCLKT_1|IOT29A|
-|-|-|GND|82|-|-|
IO|VREFB8N0|B7|DRD15|83|-|IOT18A|
IO|-|A6|DRD14|84|-|IOT25B|
IO|-|E1|GND|-|-|IOL8A|
GND|-|A1|GND|-|-|GND|
GND|-|A13|GND|-|-|GND|
IO|-|B1|NTSC_n_8375|(10k pull-up)|LPLL_T_FB|IOL6A|
IO|-|B3|NC|-|-|IOT13A|
GND|-|B8|GND|-|-|GND|
GND|-|C3|GND|-|-|GND|
IO|nSTATUS|C4|nSTATUS|(10k pull-up)|-|IOT21A|
IO|CONF_DONE|C5|CONF_DONE|(10k pull-up)|-|IOT21B|
VCCIO8|-|C6|3V3|-|-|VCCO0|
VCCIO8|-|C7|3V3|-|-|VCCO0|
VCCIO8|-|C8|3V3|-|-|VCCO0|
GND|-|D2|GND|-|-|GND|
VCCA3|-|D3|3V3|-|-|VCCX|
VCCA3|-|D4|3V3|-|-|VCCX|
GND|-|D5|GND|-|-|GND|
IO|CONFIG_SEL|D7|CONFIG_SEL|GND|GCLKC_0|IOT28B|
IO|DEV_OE|D8|(not used, sharing 10k pull-up w/ nCONFIG because routing reason)|-|-|IOT27A|
IO|-|D9|NC|-|-|IOR3B|
VCCA2|-|D10|3V3|-|-|VCCX|
IO|-|D11|NC|-|-|IOL2B|
GND|-|E2|GND|-|-|GND|
IO|-|E4|NC|-|-|IOL4A|
IO|-|E6|GND|-|-|IOT15A|
Input_only|nCONFIG|E7|10k pull-up|-|GCLKT_0|IOT28A|
IO|-|E8|GND|-|-|IOT27B|
IO|-|E9|GND|-|SSPI_CS_N/D0|IOR14B|
IO|-|E10|GND|-|-|IOR3A|
GND|-|E11|GND|-|-|GND|
IO|-|E12|GND|-|MCLK/D4|IOR12B|
VCCIO1A|-|F2|3V3|-|-|VCCO3|
GND|-|F3|GND|-|-|GND|
IO|-|F4|A3|-|-|IOL17B|
IO|TDI|F5|TDI|(10k pull-up)|TDI|IOL12B|
IO|TDO|F6|TDO|-|TDO|IOL13A|
VCC_ONE|-|F7|3V3|-|-|VCC|
IO|-|F8|GND|-|SO/D1|IOR14A|
VCCIO6|-|F11|3V3|-|-|VCCO1|
IO|CLK3n|E13|GND|-|GCLKC_2|IOR9B|
IO|TMS|G1|TMS|(10k pull-up)|TMS|IOL11A|
IO|TCK|G2|TCK|(10k pull-down)|TCK|IOL11B|
VCCIO1B|-|G3|3V3|-|-|VCCO3|
IO|-|G4|3V3|-|-|IOL17A|
IO|CLK0n|G5|3V3|-|GCLKC_7|IOL9B|
VCC_ONE|-|G6|3V3|-|-|VCC|
GND|-|G7|GND|-|-|GND|
VCC_ONE|-|G8|3V3|-|-|VCC|
IO|CLK2n|G10|GND|-|GCLKC_3|IOR17B|
VCCIO6|-|G11|3V3|-|-|VCCO1|
IO|-|G12|NC|-|SI/D2|IOR13B|
IO|VREFB1N0|H1|-|(10k pull-up)|DONE|IOL14A|
IO|-|H3|3V3|-|-|IOL20A|
IO|CLK1p|H4|GND|-|GCLKT_6|IOL15A|
IO|CLK1n|H5|GND|-|GCLKC_6|IOL15B|
IO|CLK0p|H6|3V3|-|GCLKT_7|IOL9A|
VCC_ONE|-|H7|3V3|-|-|VCC|
IO|-|H8|NC|-|MO/D6|IOR11B|
IO|-|H9|NC|-|MI/D7|IOR11A|
IO|-|H10|NC|-|-|IOR20B|
VCCIO5|-|H11|3V3|-|-|VCCO1|
GND|-|H12|GND|-|-|GND|
VCCIO2|-|J3|3V3|-|-|VCCO3|
GND|-|J4|GND|-|-|GND|
IO|-|J5|GND|-|-|IOB6A|
IO|-|J6|GND|-|-|IOB15B|
IO|-|J7|NC|-|-|IOB21B|
IO|-|J8|NC|-|-|IOB43B|
IO|-|J9|NC|-|-|IOR20A|
IO|-|J10|NC|-|-|IOR26B|
VCCIO5|-|J11|3V3|-|-|VCCO1|
IO|-|J12|NC|-|-|IOR22B|
VCCIO2|-|K3|3V3|-|-|VCCO3|
VCCA1|-|K4|3V3|-|-|VCCX|
IO|-|K5|NC|-|-|IOB6B|
IO|-|K6|NC|-|-|IOB15A|
IO|-|K7|NC|-|-|IOB21A|
VCCA4|-|K9|3V3|-|-|VCCX|
IO|-|K11|NC|-|-|IOR24A|
IO|PLL_L_CLKOUTp|L3|GND|-|-|IOL26A|
VCCIO3|-|L6|3V3|-|-|VCCO2|
VCCIO3|-|L7|3V3|-|-|VCCO2|
VCCIO3|-|L8|3V3|-|-|VCCO2|
GND|-|L9|GND|-|-|GND|
GND|-|M6|GND|-|-|GND|
GND|-|N1|GND|-|-|GND|
IO|DPCLK0|N2|GND|-|-|IOL25B|
IO|DPCLK1|N3|GND|-|-|IOL25A|
GND|-|N13|GND|-|-|GND|

***

[][cc-by-sa]

This work is licensed under a
[Creative Commons Attribution-ShareAlike 4.0 International License][cc-by-sa].

[][cc-by-sa]

[cc-by-sa]: http://creativecommons.org/licenses/by-sa/4.0/
[cc-by-sa-image]: https://licensebuttons.net/l/by-sa/4.0/88x31.png
[cc-by-sa-shield]: https://img.shields.io/badge/License-CC%20BY--SA%204.0-lightgrey.svg

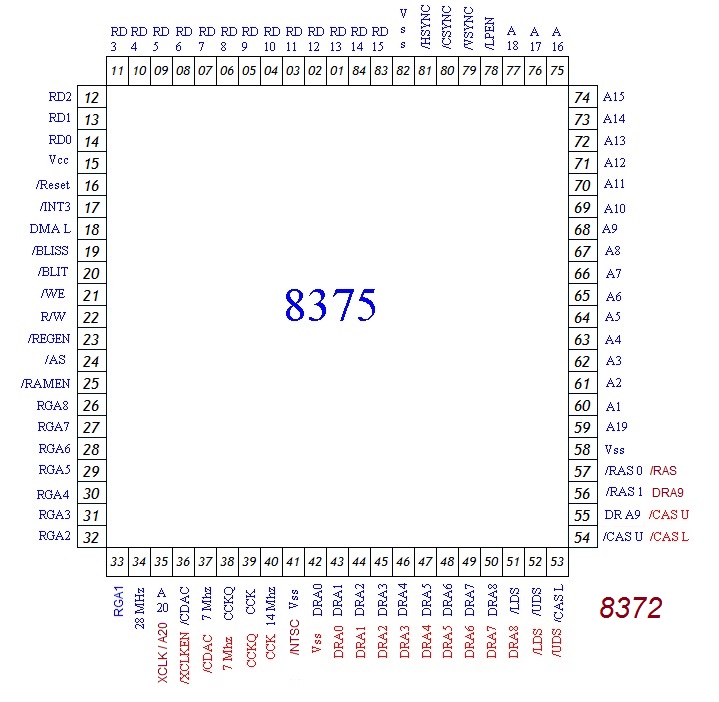
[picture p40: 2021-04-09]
images/agnus_8375_vs_8372_pinout.jpg

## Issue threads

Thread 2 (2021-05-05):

[Question] FPGA gateware

BwanaFr, 2021-05-05:
Hello,

Have-you already started to work on FPGA verilog/VHDL code?
How to contribute on this project? I've tools and competencies to assemble some prototypes.

jbilander, 2021-05-05:
Hi,

I'm working with the A314 guys now with this one. It is a hobby project. I think Niklas will give it a go with writing verilog for it, but we don't know yet if this board will fit in the Agnus PLCC-84 socket of the Amiga. A first prototype PCB has been ordered but we are still awaiting delivery. There are some documentation and also HDL written here https://github.com/nonarkitten/amiga_replacement_project/tree/master/agnus but I'm not sure of the status of that code. You can join the A314 discord to ask/know more. https://discord.gg/TGZNKnA

Regards, J

niklasekstrom, 2021-05-05:
Asking Frédéric Requin (@fredrequin ) about the status of his Agnus FPGA implementation seems like an obvious first step. If Frédéric's version is mostly working then it makes sense to use it. I'm tempted to try to put something together myself, but mostly for the learning experience.

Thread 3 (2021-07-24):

[Question]

8BitDreams, 2021-07-24:
Hello,
Nice project, one question though: why don't you use Edge Plating instead of pins?
https://www.google.de/search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

jbilander, 2021-07-24:
Hi Viktor,

It's because edge plating is very expensive in comparison. I'm trying to make ReAgnus as cheap as posssible and pin headers are very cheap. Also with this technique you effectively make your own J-leads with spring action meaning the pins can flex a little to adapt to the socket pins and give a solid connection. If it turns out this won't work for some reason then I will consider edge plating or maybe using a homebrew [PLCC-84-plug](https://github.com/jbilander/PLCC-84-plug) like in https://thezippsterzone.com/2019/03/27/gime-x/

Regards,
Jörgen

kipper2k, 2021-09-09:
Progress looks good, i do like the idea of the wraparound pin header. Is the chip going to be "the one" if so i will buy a couple and test this out (if i can find them lol.) Good job!

vitecd, 2022-08-10:
Hello,
How is it going? Did you test it yet?

jbilander, 2022-08-10:
Hi,

yes, Niklas has got it working. At least with a 10M16 FPGA.
I only did the hardware design, he has done the hard part with actually implementing the Agnus logic in Verilog, which is not an easy task. You will have to ask him for details.

nonarkitten, 2022-08-10:
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
I found that even without edge plating, it makes good contact. These were made by JLCPCB and there's surprisingly good continuity between them. I'm worried at how consistent this might be, but it's a start.

kipper2k, 2022-08-10:
I think with a little "creativity" we can make it happen

niklasekstrom, 2022-08-10:
@nonarkitten That looks very interesting!

What FPGA is that board using? Are there voltage level translator chips on the back side?

Can you take another photo that zooms in on the connections between the PCB and the PLCC socket? It's hard to see in the above photo as the connections are slightly out of focus.

Let us know if we can assist in some way. I adapted Minimig's Agnus implementation to ReAgnus and that seemed to work well. I suppose frenchshark is working on a more faithful implementation, which sounds like a good idea.

nonarkitten, 2022-08-10:
> @nonarkitten That looks very interesting!
>
> What FPGA is that board using? Are there voltage level translator chips on the back side?

No.

Long story short, officially, the low-voltage ispMACH is 5V tolerant, the MachXO PCI pins are 5V tolerant with series resistor and the MachXO2 isn't at all. However, the IBIS model seems to imply that they're all the same two types of sysIO pins with some having strong clamping diodes and some (e.g., the so-called LV or PCI) having weak clamping diodes (all the rest) which are about 1/2 the current capacity of the strong ones.

I suspect they're all basically the same and Lattice hasn't bothered recertifying them for 5V (it is dead after all, right? Only STM and Cypress seem to care). Fun fact, I drove the UART on my AM3358 at 5V for days (hooked to an Arduino) and it caused no problems. It's all about the current.

This would imply that they are *all* 5V tolerant as long as we're under the clamping current. But when places say 5V tolerance they have to mean a real, full on 5V CMOS. But we know the Amiga is not "true" 5V it's pseudo-NMOS (~10K or 100K equivalent pull-up) or real NMOS with 4.7K pull ups. It is 5V TTL which is why the CBT[D]s work so well.

These signals already have crappy amounts of current reaching the pins so I'm almost leaning to them not being needed AT ALL on the Amiga. We're going to try that. Worst that happens, I release the magic smoke and try with them.

> Can you take another photo that zooms in on the connections between the PCB and the PLCC socket? It's hard to see in the above photo as the connections are slightly out of focus.

This is the limit of my iPhone. I'll charge up the EOS and see if it can do better.

> Let us know if we can assist in some way. I adapted Minimig's Agnus implementation to ReAgnus and that seemed to work well. I suppose frenchshark is working on a more faithful implementation, which sounds like a good idea.

I've looked at both and they're both semi-close. Having the schematics has helped and yeah, he's been working on redoing Agnus since we got them. I haven't looked closely enough at MiniMig's Agnus, but if it's Paula and Denise are any indication, there are probably some gross inefficiencies in there. I know timing is a mess.

Paula used multipliers for the 8-bit data and 6-bit volume when in reality it's just a 3.58MHz PDM and 55kHz PWM, AND-ed. The 8-bit is the carry out of an 8-bit adder and the final left/right out is a 2-bit adder of those. Saves tones of LUTs.

Denise strangely had the pixel bus MUX on the RGB side and splits the HAM and CLUT into two different blocks. The pixel bus should be MUXED before then and you can save a ton of LUTs merging the HAM and CLUT blocks into one.

But god, I'd kill to get the Denise and Paula schematics from Jeri.

And don't get me started on it's broken Gary implementation scattered all over the place. Getting my Gary board to work 100% revealed how utterly broken that is. </rant>

Where FrenchShark's implementation is nice is the SDRAM controller and DMA cache. I wanted to squeeze in some 133MHz pSRAM to substitute for motherboard DRAM and the timing is PRETTY tight to remain synchronous, so I've been reading up on how it works with SDRAM.

nonarkitten, 2022-08-10:
LOL. Might need to clean the lens; there's a little bloom here.
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

niklasekstrom, 2022-08-10:
> These signals already have crappy amounts of current reaching the pins so I'm almost leaning to them not being needed AT ALL on the Amiga. We're going to try that. Worst that happens, I release the magic smoke and try with them.

Testing that sounds like a good plan!

> I haven't looked closely enough at MiniMig's Agnus, but if it's Paula and Denise are any indication, there are probably some gross inefficiencies in there. I know timing is a mess.

See, this is where we differ. 😄 I couldn't care less about the implementation being inefficient, as long as it fits in the FPGA and has the same (correct) externally observable behaviors.

> LOL. Might need to clean the lens; there's a little bloom here.

These pictures are a lot clearer, thanks! That looks really good.

nonarkitten, 2022-08-10:
> > These signals already have crappy amounts of current reaching the pins so I'm almost leaning to them not being needed AT ALL on the Amiga. We're going to try that. Worst that happens, I release the magic smoke and try with them.
>
> Testing that sounds like a good plan!

I will put everything on the ARP git site.

> > I haven't looked closely enough at MiniMig's Agnus, but if it's Paula and Denise are any indication, there are probably some gross inefficiencies in there. I know timing is a mess.
>
> See, this is where we differ. 😄 I couldn't care less about the implementation being inefficient, as long as it fits in the FPGA and has the same (correct) externally observable behaviors.

I know, I'm a bit of a perfectionist here, but there may be compatibility corner cases that come from fixing this. Good enough counts with emulators, but I'm trying to preserve the original chips and that means copying the logic as close as we can as well (with clear limitation on the differences between FPGA and ASIC in mind).

That and size. Large FPGA are insanely overpriced right now and there's no good reason Agnus needs more than about 1300 LUTs, maybe a lot fewer. It's narrowly too big (probably) for the 1200 LUT version of the MachXO2, but the 2000 LUT version is plenty.

Anyway, I just came to show that edge plating isn't THAT hard and seems to work, not co-opt someone else's project.

kipper2k, 2022-08-10:
I have a chip coming so i will build the beta and hopefully no smoke :)

jbilander, 2022-08-10:
Great work nonarkitten!

Hopefully that edge-plating isn't too expensive?.

If that FPGA doesn't work out for some reason then perhaps this Gowin, link  below, could be a good replacement, 100 pin LQFP (79 IO) 4608 LEs and size 16x16 mm (pitch 0.5 mm). Easy to solder and 3.3V (The -UV versions are with built-in LDO for the 1.2V-core so you don't have to think about that when designing, only one 3.3 volatge regulator required). IO-pins can be set to LVTTL 3.3 in the tool, but you will need level shifters towards the Amiga I think.

https://eu.mouser.com/ProductDetail/GOWIN-Semiconductor/GW1N-UV4LQ100C6-I5?qs=wnTfsH77Xs6vp00qFbqNlg%3D%3D

Expected in stock 30-sep-22 :)

I'm using a Gowin FPGA in another Amiga-hobby-project at the moment and it works great so far. The dev. tools are very snappy to work with compared to Xilinx ISE 14.7 for example.

These are the different Gowin FPGA versions at the moment:

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

Regards

jbilander, 2022-08-11:
These are the Gowin FPGAs I had in mind for ReAgnus.

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

Notice how it says 80 I/O. That is exacly the amount of IO-pins needed for Agnus, four pins in Agnus are Power-pins (VCC/GND), but that would require to use all JTAG-pins etc as IOs which is possible...

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

Unfortunately the pinout differs between the two, so no easy upgrade/downgrade path, but I guess you could try and synthesize and see if it'll fit in a -UV2 and if that is the case then go with that one in the design (if you can source them from e.g. Mouser?).

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

jbilander, 2023-03-22:
For information, the latest design 837X Rev 1C is now updated with castellated holes (branch _castellated_holes_) and should be able to take a Gowin GW1N-UV9UG169C6/I5 as a drop-in replacement for the Intel 10 Max. Gerbers exist under _Releases_ as pre-release and is completely untested. Would be fun to try though.

Pin assignment here:
https://github.com/jbilander/ReAgnus/tree/main/docs

JLC can do assembly of this Gowin FPGA via the Global Sourcing function.

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

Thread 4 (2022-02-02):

Applicability to the other Amiga custom chips

DavidGriffith, 2022-02-02:
How much of this do you expect this project to be directly applicable to producing similar hardware for the other Amiga custom chips?

jbilander, 2022-02-02:
Hi,

FPGA re-implementation of the custom chips Denise, Buster and Gary is already done (not by me) and the 8250 CIA is being worked on by a couple of persons, for example Niklas. Left to-do is Paula, but I think no [publicly available schematics](https://github.com/nonarkitten/amiga_replacement_project) exists of her and that is why she hasn't been implemented as a drop-in replacement by anyone so far. There is no point in designing a PCB for Paula if there's no one who knows how to implement her in HDL (as a standalone chip). Paula was implemented in the minimig project but that is together with the other custom chips in the one and same FPGA, a standalone drop-in replacement is a different beast.

Denise (Martin Åberg, https://github.com/endofexclusive/deniser)
Gary (Matthias Heinrichs, https://gitlab.com/MHeinrichs)
Buster (Matt Harlum, https://github.com/LIV2/Bluster)
CIA (Niklas Ekström, https://github.com/niklasekstrom/cia-verilog)

niklasekstrom, 2022-02-02:
I think Frederic Requin mentioned that his Paula implementation (https://github.com/nonarkitten/amiga_replacement_project/blob/master/paula/Paula.v) has been tested to work as a stand-alone chip.

Otherwise adopting the Paula code from Minimig (https://github.com/MiSTer-devel/Minimig-AGA_MiSTer/tree/MiSTer/rtl) should be doable.

DavidGriffith, 2022-02-02:
I'm aware of those other projects doing fpga reimplementation.   I was curious about the other half of such efforts, the creation of physical hardware to receive the programming and then drop into an Amiga.

jbilander, 2022-02-03:
Hi,

The creation of the physical hardware, designing a PCB with an FPGA and some level shifters, is the easy part in this case. The hard part is to implement the HDL so that the FPGA behaves just like the original chip produced by Commodore, not to mention all the testing needed to verify that it is 100% compatible. Often you need timing diagrams/specifications/equations or you'll have to do some serious trial and error reverse engineering of all the signals from the original chip. That is very time-consuming work.

mbtaylor1982, 2022-12-21:
@jbilander I'm working on a reimplementation of the SDMAC rev4 and wanted to see if you'd be interested in helping adapt this design for that purpose. The Verilog is at an advanced stage and my test bench code shows several of the modules appear to work as expected.  if interested let me know.

jbilander, 2022-12-23:
Hi, great work. I have limited time right now since I focus my spare time on development for the SF2000 card, but I can help if you have questions and perhaps later in a month or so I will have more spare time to help adapt a PCB design. The Intel 10 Max FPGAs are not in stock anywhere, and that has been the case for a long time now, so the first thing you need to decide on is what FPGA to use. Also BGA-packaging is not so DIY friendly, so that is worth considering as well when designing. Right now Trion and Gowin FPGAs are available.

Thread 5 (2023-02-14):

Flashing the FPGA

Syntec1, 2023-02-14:
Hi,

I understand this is a work in progress project, I would like to build 2 to test on a A2000 and A500.
unfortunately I had a denied response for the other project.
I am willing to share the info on the build, flash and testing from my end, and yes I'm experienced in building such boards.
Maybe I missed it but I don't not see the code for flashing the FPGA, or is it yet to be created or still in development phase?
If it is not possible to participate then at least I tried :)

jbilander, 2023-02-15:
Hi, this repository is only the hardware design, the PCB.
Niklas Ekström has been successful at writing HDL for it and making it work in a 10M16SCU169C8G FPGA, you will have to ask him about firmware.
The problem is the Intel Max 10 FPGAs have not been available and are still not available to source from anywhere since over two years now.

niklasekstrom, 2023-02-15:
Hi guys,

Yeah over a year ago I was hacking on the HDL for ReAgnus and got a modified version of [Minimig's Agnus implementation ](https://github.com/MiSTer-devel/Minimig-AGA_MiSTer/tree/MiSTer/rtl) to run. Here is a picture of it running Silkwork: http://eab.abime.net/showpost.php?p=1544845&postcount=17

The problem I experienced with the ReAgnus design was that I felt it was mechanically unstable. And then as Jörgen mentioned, the Intel Max 10 has been virtually impossible to buy the last year. Both of those issues are addressed by a new design by Jörgen, ReAgnus-MegAChip, which is currently in a private repository since it hasn't been tested yet, but will hopefully be tested "soon".

I am not inclined to release the HDL I have written until we have a version of both hardware and HDL that I believe people can build and be happy with.

If you like then perhaps we can setup a Discord server where we can discuss ReAgnus development, and then maybe that will help move the development along at a faster pace?

nonarkitten, 2023-03-24:
You weren't "denied" anything @Syntec1

Syntec1, 2023-03-24:
English is not my native language, Excuse me for expressing it incorrectly.

thbreidenbach, 2024-05-30:
Hey there, are there any news on the firmware side or in establishing a Discord for Disussion? On Hardware side there could be several options including a removable low profile version without a socket (Using https://www.mouser.de/ProductDetail/575-3016015152127 after removal of the Agnus Socket) This way even a common PLCC Socket can be placed when needed.

nonarkitten, 2024-05-31:
He has a github page for it.
https://github.com/fredrequin/AliceRE

On Thu, May 30, 2024 at 10:37 AM Jorgen Bilander ***@***.***>
wrote:

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

thbreidenbach, 2024-05-31:
Yeah, found that but unfortunately there's no firmware release yet.

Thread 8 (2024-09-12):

May i help you?

PizzaDellaCasa, 2024-09-12:
Hello jbilander,

I am new to github, so this may not be the right or best place to get in contact with you. If there is a better way, please give me a hint.

I registered here, because I am curious about the ReAgnus project. I stumbled across this project, while looking for a replacement for an defective 8372A. I was always interested in rebuilding old chips in FPGA/CPLD, but never focused on that topic. So now i have some kind of a motivation for that :).

So I would like to ask, if i can participate/help/learn to contribute to your efforts and the efforts of nonarkitten and niklasekstrom.

There is a discord server mentioned in one of your discussions. Would that be an option to get in contact with you guys?

Hope to read from you soon.

Sincerely

PizzaDellaCasa

jbilander, 2024-09-12:
Hi,

The latest hardware Rev. 2E was verified OK by Niklas a week ago or so. He tested his old Verilog source code modified for the latest pin assignment of ReAgnus and it worked. However he is focusing on adapting it to his own hardware design based on a Efinix T8 FPGA. You can get in contact with his project here (link to discord in there I think):  https://www.a1k.org/forum/index.php?threads/91724/

If you are serious and want to develop an open source firmware for this hardware and are an experienced Verilog/VHDL developer with great knowledge about the Amiga internals and how to write down Agnus in HDL I can probably build you a development board and a ReAgnus unit for cost of components. I have spare PCBs at home but would have to order some components. You can check link here how the devboard looks like: https://eab.abime.net/showpost.php?p=1703451&postcount=335

Let me know...

Regards, J

PizzaDellaCasa, 2024-09-12:
Hello jbilander,

thank you for your reply. As I wrote: I would like to participate, help and on that road learn and improve.

Yes, I have some background in electronics and hardware development. So I am quite familiar to KiCAD. I am also familiar to Verilog and VHDL and I have some experience with some Lattice, Intel (Altera) and AMD (Xilinx) components. Also I would like to contribute to the open source community, that helped me in the past a lot.  But I am new to Amiga internals. The need for a 8372A could be a perfect reason to get into that topic.

First and foremost I would need a starting point on code base, Agnus functionality, actual hardware in discussion and direction of development in the community. On that road, someone to discuss that topic would also be very much appreciated :).

For firmware, I already had a look in the repos of nonarkitten, but could not get an overview or an idea where to start. Nor what CPLD/FPGA is actually in discussion. Minimig also seems to be the base for another branch of development.

For hardware, I had a look into your repo too (that is why I am here in the first place). But i guess, your work is already very much completed. The only thing in discussion seems to be the mechanical stability. Or am I missing out something?

So my question is: Could you or someone else please provide me with some hints to relevant actual repos, discussions, community members, communication channels or documentations to get me on track in a short cut? After that, I would like to know, where I can be of any help for the project.

So i guess, ReAgnus development boards are not of any urgent need. But thank you for your kind proposal. I guess I will return to that offer in the near future.

Regards

niklasekstrom, 2024-09-12:
Hi PizzaDellaCasa,

Feel free to join the discord server that Jörgen linked to (https://discord.gg/Tue5K9PM2W). There you can discuss this topic, and join me in working on the Verilog logic I have so far.

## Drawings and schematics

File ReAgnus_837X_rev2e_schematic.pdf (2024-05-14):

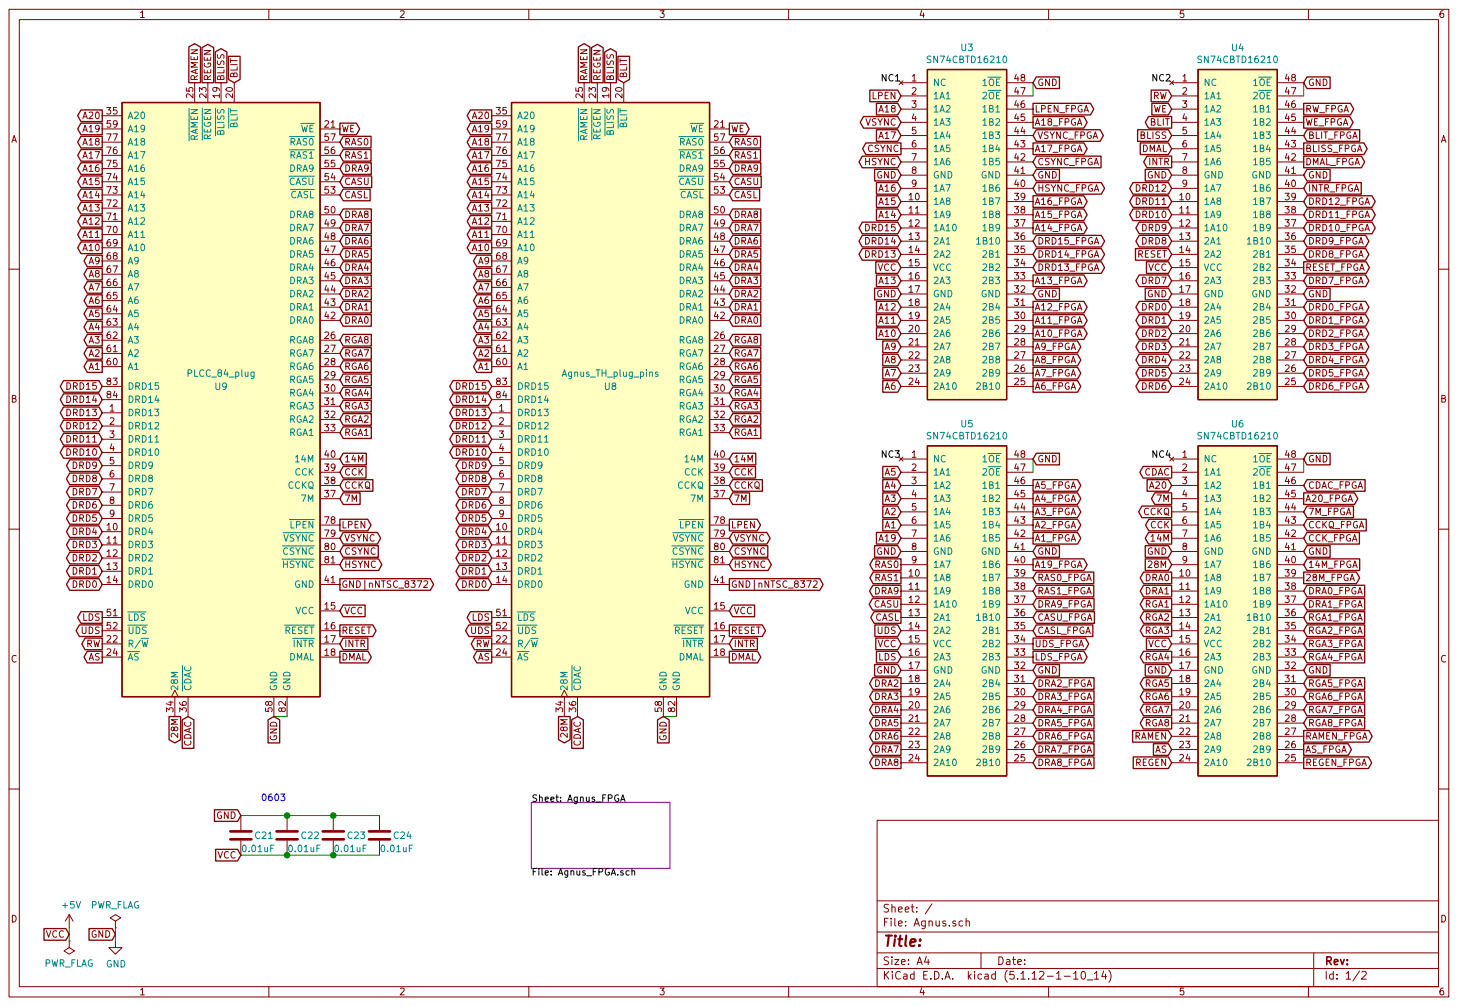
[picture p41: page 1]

File: Agnus.sch Sheet: / Sheet: Agnus_FPGA

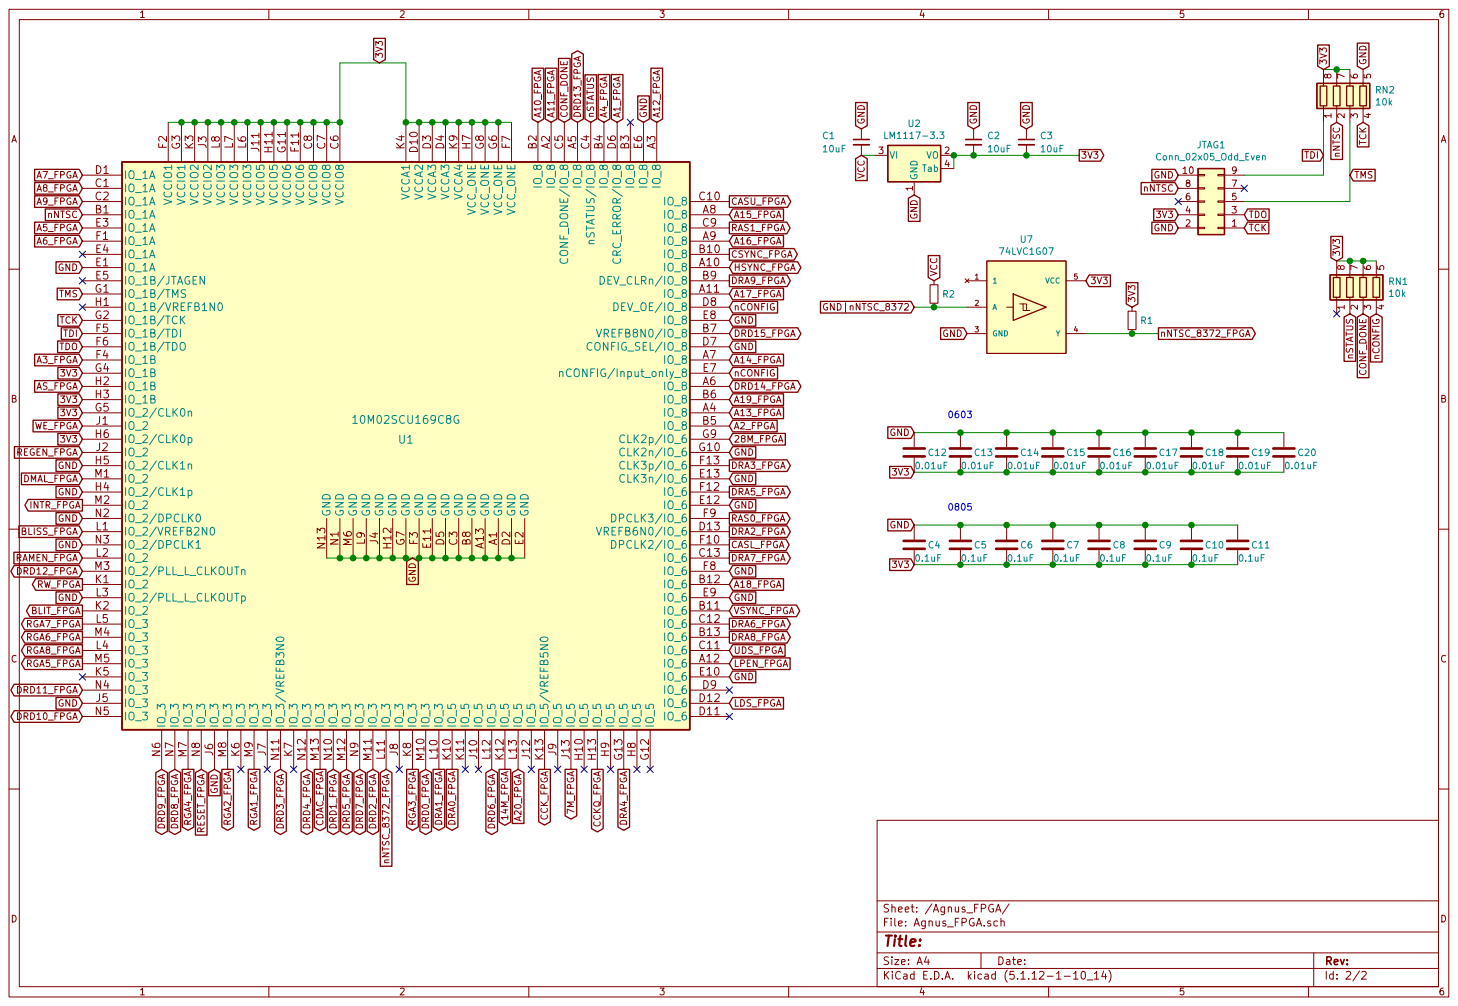
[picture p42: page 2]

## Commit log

2021-03-26 added KiCad files
    [Agnus.kicad_pcb, Agnus.sch, Agnus_FPGA.sch]
2021-03-28 Updated routing, unused CLK pins to GND, added more caps
    [Agnus.kicad_pcb, Agnus.sch, Agnus_FPGA.sch]
2021-03-30 VCC/GND improvements, added 3V3 filled zone, added testpad with conn to E1
    [Agnus.kicad_pcb, Agnus_FPGA.sch]
2021-03-31 cleanup and improved routing, added testpin/debugpin with conn to L11
    [Agnus.kicad_pcb, Agnus_FPGA.sch]
2021-04-08 added 10k pull-up on JTAG pin 8
    [Agnus.kicad_pcb, Agnus_FPGA.sch]
2021-04-20 Removed castellated holes, adjusted size and board edges, changed to 0.4/0.2mm vias, centered vias in BGA-pads.
    [Agnus.kicad_pcb, Agnus.sch]
2021-04-20 Reassigned A7_FPGA, A8_FPGA to D1 and C1, reassigned pad B1 as debug-pin to JTAG free pin 7 (NC)
    [Agnus.kicad_pcb, Agnus_FPGA.sch]
2021-04-20 Changed to clearance 0.254mm on 3V3 filled zone
    [Agnus.kicad_pcb]
2021-04-20 added a GND and a 3V3 via
    [Agnus.kicad_pcb]
2021-04-20 fixed outline zones for all layers
    [Agnus.kicad_pcb]
2021-04-20 fixed all silkscreen positioning
    [Agnus.kicad_pcb]
2021-04-22 Made custom footprint with smaller pads 1.0mm -> 0.8mm, allowing for more centered TDO and CASL vias
    [Agnus.kicad_pcb, Agnus.sch, Agnus_FPGA.sch]
2021-04-23 Added more decoupling caps, changed to 6 mil copper pour clearance, added some more 3V3/GND vias, improved routing.
    [Agnus.kicad_pcb, Agnus.sch, Agnus_FPGA.sch]
2021-04-24 Beveled 45-degree Cut off Corners. Improved a GND via.
    [Agnus.kicad_pcb]
2021-04-24 Added more decoupling caps
    [Agnus.kicad_pcb, Agnus.sch, Agnus_FPGA.sch]
2021-05-31 changed from 0.4 mm to 0.5 mm thru_hole in pads
    [Agnus.kicad_pcb]
2021-06-05 Shrunk board side to 28.9 mm, new design with angled pin header pins soldered and folded around board edge. 5 mil routing where needed.
    [Agnus.kicad_pcb]
2021-06-05 corrected VCC pin connection
    [Agnus.kicad_pcb]
2021-06-05 Update footprint
2021-06-27 rev1b silkscreen change
    [Agnus.kicad_pcb]
2022-02-03 added 3D-model of cay16-103j4lf
    [Agnus.kicad_pcb]
2022-09-05 added footprints
2022-09-05 re-design with edge-plating and universal 837X-Agnus, one Agnus for both variants of pinout
    [Agnus.kicad_pcb, Agnus.sch, Agnus_FPGA.sch]
2022-09-06 small fixes, improved grounding for U5, re-labeled buffer chip to U7, silkscreen fix
    [Agnus.kicad_pcb, Agnus.sch, Agnus_FPGA.sch]
2023-03-15 changed D2,E2 from NC to GND, D3 from NC to 3V3
    [Agnus.kicad_pcb, Agnus_FPGA.sch]
2023-03-15 Added pull-up for H1-pin (Gowin DONE-pin) to free pin in RN1-resistor pack.
    [Agnus.kicad_pcb, Agnus_FPGA.sch]
2023-03-15 Moved 28M_FPGA CLK input from G5 to G9-pin and made G5,G10 NC.
    [Agnus.kicad_pcb, Agnus_FPGA.sch]
2023-03-17 updated footprint
    [Agnus.kicad_pcb]
2023-03-17 added footprint for castellated holes
2023-03-17 switched to footprint made for castellated holes
    [Agnus.kicad_pcb, Agnus.sch]
2023-03-17 fixed routing for adjusted footprint
    [Agnus.kicad_pcb]
2023-03-17 L3,N2,N3,H4,H5,H6 set to NC instead of GND
    [Agnus.kicad_pcb, Agnus_FPGA.sch]
2023-03-17 F12 set to NC instead of GND
    [Agnus.kicad_pcb, Agnus_FPGA.sch]
2023-03-17 Added vias as castellated holes for all 84-leads
    [Agnus.kicad_pcb]
2023-07-30 Updated design to accommodate a PLCC-84-plug
    [Agnus.kicad_pcb, Agnus.sch, Agnus_FPGA.sch]
2023-07-30 small silkscreen fix adding pin 1 indicator
    [Agnus.kicad_pcb]
2023-07-30 Added 3D-model of PLCC-84-plug for ReAgnus Rev.2A
    [Agnus.kicad_pcb]
2023-07-30 fixed positioning of 3D-model PCB for homebrew PLCC-84-plug
    [Agnus.kicad_pcb]
2023-07-30 Added Rev.2A schematic pdf
2023-10-12 Added custom BGA-169-footprint with 0.35mm Pads
2023-10-12 Replaced 0.4/0.2 mm Vias with 0.45/0.2 mm Vias and re-routed, some BGA-pin-assignment changes were made
    [Agnus.kicad_pcb, Agnus_FPGA.sch]
2023-10-12 Added rev2b schematic pdf
2023-10-23 small cosmetic fix of RGA2 trace
    [Agnus.kicad_pcb]
2024-02-18 Removed CONFIG_SEL and repurposed trace for nCONFIG pull-up routing it through D8 to reach E7 (nCONFIG pad)
    [Agnus.kicad_pcb, Agnus_FPGA.sch]
2024-02-18 Assigning 3V3 to unused clock inputs H6, L3 and GND to H4, N2, N3, G10, E13 and for better grounding to J5, J6, E12, swapped position of TCK and TMS in resistor array
    [Agnus.kicad_pcb, Agnus_FPGA.sch]
2024-02-18 Added schematic pdf
2024-04-15 Improved routing, E1,L3 set to GND, removed debug-pin, E4,E5 set to NC, moved A3_FPGA to pad F4, Removed DONE-signal (not needed).
    [Agnus.kicad_pcb, Agnus_FPGA.sch]
2024-04-15 removed old schematic pdfs
2024-05-14 Added pull-up resistor (R2) to VCC for pin 41, added JLCJLCJLCJLC to silkscreen for orderno placement, bumped version to Rev. 2E
    [Agnus.kicad_pcb, Agnus_FPGA.sch]
2024-05-14 silkscreen fixes
    [Agnus.kicad_pcb]
2024-05-14 Add schematic pdf
2024-05-17 small fix/improvement adding a second GND-via for pin 47,48 on U4
    [Agnus.kicad_pcb]
2024-07-01 Corrected values for capacitors C4,C5,C8,C11 to 1uF and the reference for the Winslow plug to U8 to match the BOM
    [Agnus.kicad_pcb, Agnus.sch, Agnus_FPGA.sch]
2024-08-15 Corrected C20 value from 0.01uF to 0.1uF
    [Agnus.kicad_pcb, Agnus_FPGA.sch]
2024-08-31 add pin-assignment picture

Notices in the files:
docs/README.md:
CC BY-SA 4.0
